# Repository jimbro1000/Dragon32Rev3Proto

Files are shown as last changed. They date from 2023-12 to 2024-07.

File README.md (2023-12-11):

# DRAGON 32 RECREATION Rev 3 #

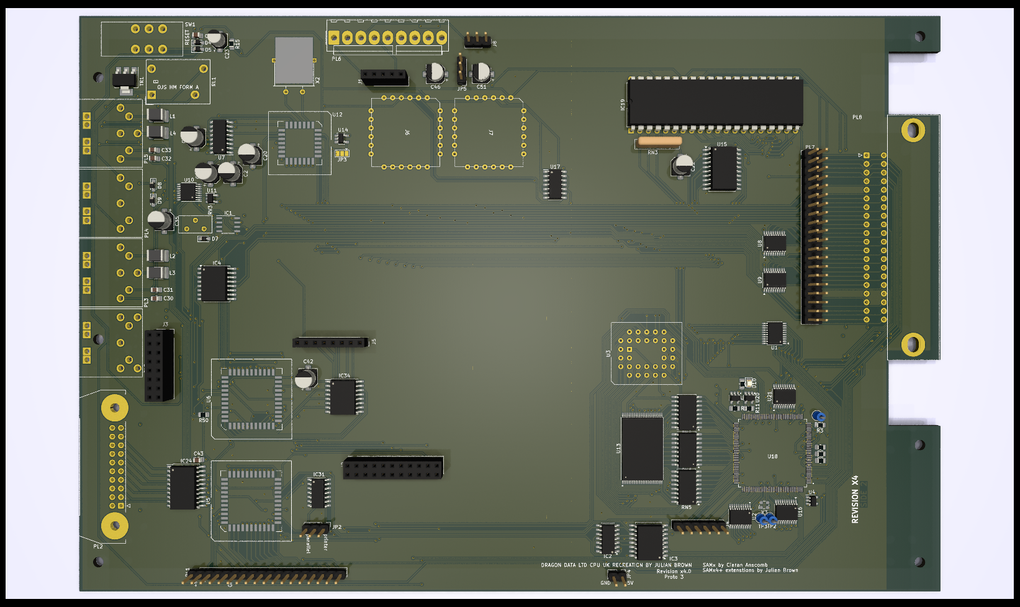
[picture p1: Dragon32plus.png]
Dragon 32 revision 3 render


This project started as a recreation of the SA2120 CPU Mainboard
for the 1982 Dragon Data **Dragon 32**

Everything (excluding modifications) is taken from the SA2120
schematics. Where this version changes is the move to surface
mount components which radically alters the size of each part
along with a move to using SRAM instead of DRAM. The intention
is that the board should be supplied fully or semi-populated
leaving just optional (socketed) components to be fitted.

The ROM is now a single 28C256 eprom with an option to switch
between two images using JP6 or to allow the rom to be
automatically selected from the PIA. In effect this allows the
computer to operate as a D32 but with two different images or
as a D64.

The video circuits have been isolated from the rest of the
board to improve output quality.

To maintain compatibility with the D64 there is an optional
serial port. This needs to be enabled by bridging a solder
jumper (JP3) to position 1-2. If the serial port is not
being populated it should be position 2-3. By default this
is not bridged and the computer will not function without
the jumper being set. If the supporting SMD ICs at U13 and
U14 are fitted the jumper can safely be left in position
1-2 regardless of whether the 6551 UART chip is fitting.

If you are fitting the board into an
early D32 case the serial port would be completely covered
without modifying the case. Later D32 cases had all four
ports but the fourth (serial) port blanked off internally.

A second (internal) cartridge port has been added, by way of
a 2x20 header, along with an additional +5V/Gnd pickup point
for further internal expansion. The keyboard connector also
has two additional pins that can supply 5v to the keyboard,
the extra pins are on the left. The keyboard should always 
be fitted to the right to avoid any shorts.

The board incorporates a replacement to the SAM chip based on
Ciaran Anscomb's SAMx4 design which in turn includes Stewart
Orchards 256k banker board 
<https://gitlab.com/sorchard001/dragon-256k-banker-board>

A custom VHDL is needed for this. Do not use the code from
Ciaran's site as it won't work.

The VHDL has potential (untried as of yet) to allow the
board to run permanently at double speed without loss of
a working display. The potential extends to running at 4x
speed but this is subject to using a suitable CPU and SRAM.

Because all of the CPU speed control is managed by the CPLD
replacing the SAM it is possible to change and update the
VHDL programming to include new features provided they do
not need changes to the board itself. Running at x4 speed
would require a different oscillator at X1 but would not
need other changes. All of the specified components are 
modern high performance equivalents and should be easily
able to cope with the high clock frequencies.

The board also includes three PIAs but only the first two are
necessary for normal usage. The third PIA (U7) is used by some
of the video daughterboards to provide additional functionality
such as a programmable character "rom".

All of the PIAs are changed to the W65C21 chip instead of the
MC6821. These chips work at higher frequencies and conveniently
use a smaller PLCC package

## Progress ##

In the current state (3.0) only the basics of the board have
been tested and proven. 

To be tested:

* SRAM conversion
* Serial port
* PIA 3
* SAMx4

## Modifications ##

### Joysticks ###

The two joystick ports provide a second fire button capability
wired to consecutive keyboard rows, as per the Tandy CoCo.
Unless a two button joystick is used this make no difference to
the operation of the computer. It also requires the use of 6-pin
DIN sockets, these are pin compatible with the 5-pin originals
so a regular single button joystick can still be used.

The two extra buttons can also be disabled by omitting L3 and L4.

### Parallel Port ###

A jumper (JP2) has been introduced to bypass the logic inverter
on the STROBE line. When bypassed the parallel port should
operate as a communication port for DRIVEWIRE.

### Memory Addressing ###

The board is configurable between 32k and 64k ram addressing
using jumper JP1. In most scenarios there is no reason to
disable the 64k option.

### Video PIA ###

One of the possible features of the board is to support an
extended version of the video circuitry to include 
external character ram. Adding a third PIA to the board takes
a little refinement of how PIAs are interfaced. In this case
the mapped memory for PIA1 is broken into 8 blocks, this first
maps to the original memory space for PIA1 while the other 7 
are effectively available to more registers. On this board
only the first of those 7 is used (yet). This makes addresses
$FF44-$FF47 map to the new PIA (referenced here as 1b).

Register A of PIA1b is control of additional functions  
bit 0 controls internal or external character image generation  
bit 1 controls automatic invert on bit 6 of the data bus  
bit 2 is manual control of the invert signal  
bit 3 controls automatic semigraphics on bit 7 of the data bus  
bit 4 is manual control of the semigraphics signal  
bit 5 opens the external character ram to writing  
bit 6 is a clock trigger to the external character ram address  
bit 7 is unused (proposed to be CoCo compatibility switch for 
the keyboard)  

Register B of PIA1b is used for programming the external
character ram data.

The external character ram can only be programmed while the
video is set to the internal character data of the 6847.

### Serial Port ###

The board includes the serial port capability originally
added to the D64. This adds a dedicated 6551 UART chip
to the machine allowing serial communications at higher
speeds without locking out the CPU. The port is optional.

To allow this to work the board *must* user a D64 power
board that supplies -12V instead of -5V. It is possible
to rig the board to work by bridging two pins (2 and 3)
of REG1 but this is not the intended mode of operation.
If the board is rigged for -5V supply then REG1, C18
and C19 must be left unpopulated.

## Substitutions ##

All of the components specified with the exception of
the CPU are current and should be readily available.
Supplies of 6809 CPUs are still plentiful but are all
NOS.

The Hitachi HD6309 is usable but may cause crashes in 
some software due to lazy coding. It is however still 
made thanks to usage in old military equipment in at
least one country.

### The Future ###

The board may look empty in its current form but the design
is dominated by the main data and address busses.

The design will also include two AY8912 audio chips to 
provide stereo sound. This brings utilisation of the 
additional device addressing to 50% but also fills up
the remainder of the board.

It is possible to increase the size of the board along
the bottom edge as the current design complies with the
original D32 design rather than the enlarged D64 board.

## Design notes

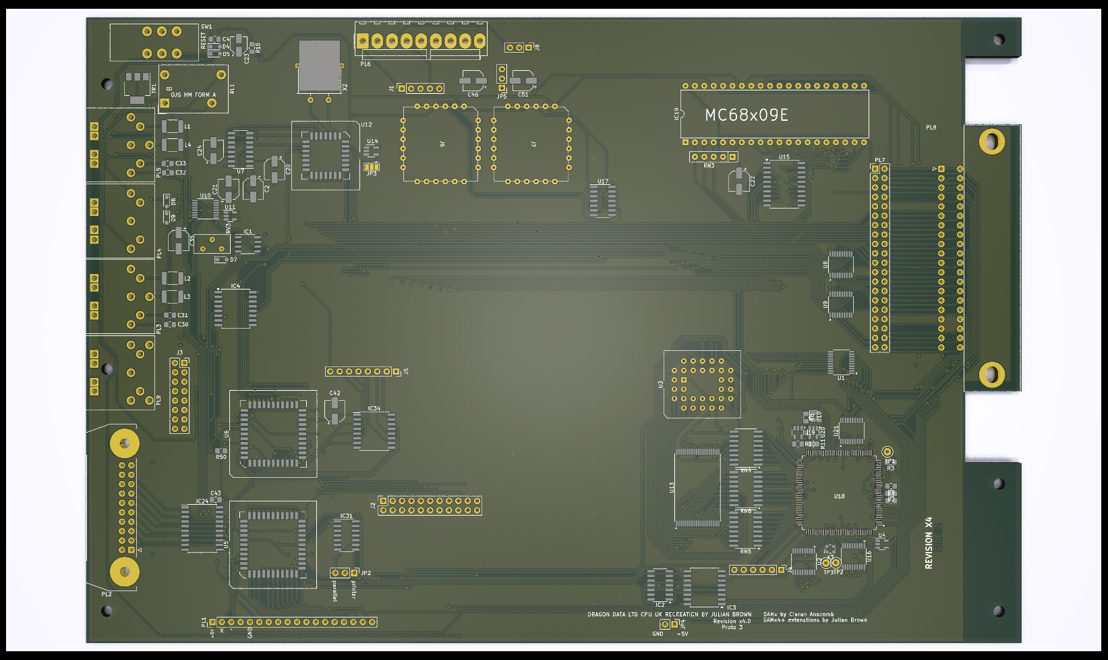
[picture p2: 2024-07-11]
Dragon32.png

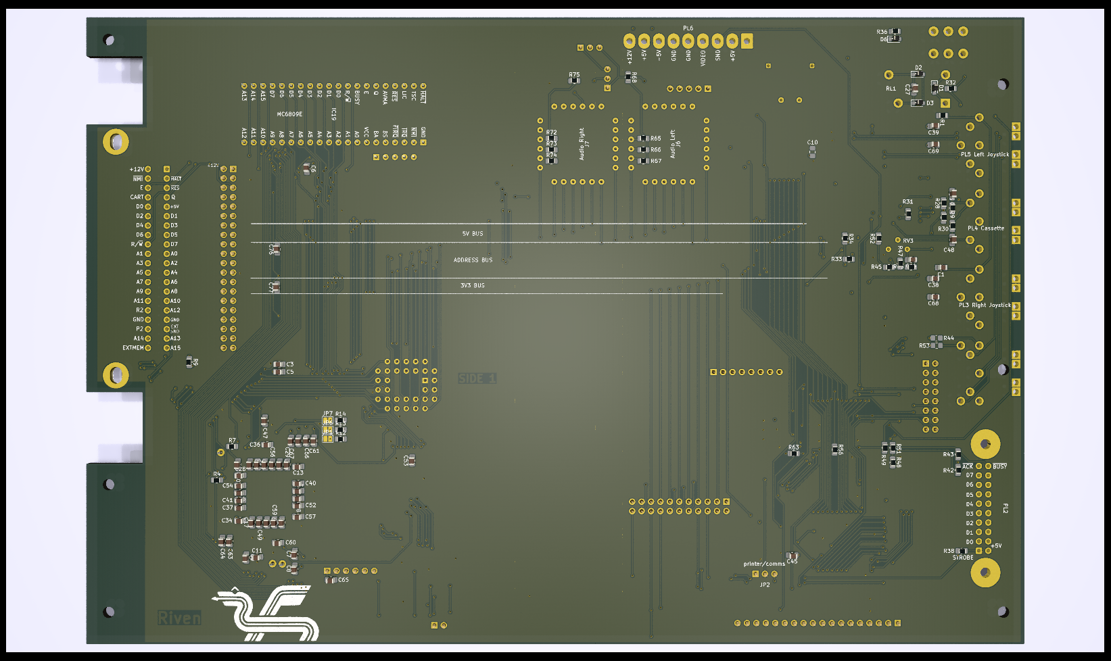
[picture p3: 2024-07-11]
Dragon32plusR.png

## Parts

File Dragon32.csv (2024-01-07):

Source: | C:\Users\jimbr\OneDrive\Documents\KiCad\7.0\projects\Dragon32Alpha3\Dragon32.kicad_sch
Date: | 17/12/2023 11:29:43
Tool: | Eeschema 7.0.6
Generator: | C:\Program Files\KiCad\7.0\bin\scripting\plugins/bom_csv_grouped_by_value.py
Component Count: | 183
Collated Components:
Item | Qty | Reference(s) | Value | LibPart | Footprint | Datasheet | DNP | DigiKey | JLCPCB BOM | LCSC Part | Mouser | Note | SA2120 | Toby
1 | 7 | C1, C38, C39, C43, C45, C68, C69 | 0.01uF | Device:C_Small | Capacitor_SMD:C_0805_2012Metric_Pad1.18x1.45mm_HandSolder | https://www.vishay.com/docs/45171/kseries.pdf |  | BC2662CT-ND
2 | 3 | C2, C35, C42 | 10uF | Device:C_Polarized_Small | Capacitor_SMD:CP_Elec_5x5.3 | https://www.we-online.com/katalog/datasheet/860010372001.pdf |  | 732-8593-1-ND
3 | 4 | C3, C4, C5, C27 | 0.1uF | Device:C_Small | Capacitor_SMD:C_0805_2012Metric_Pad1.18x1.45mm_HandSolder | https://www.vishay.com/docs/45171/kseries.pdf |  | BC1101CT-ND
4 | 1 | C6 | 4.7uF | Device:C_Polarized_Small | Capacitor_Tantalum_SMD:CP_EIA-3216-18_Kemet-A_Pad1.58x1.35mm_HandSolder | https://datasheets.kyocera-avx.com/tap.pdf |  | 478-8984-1-ND
5 | 7 | C7, C11, C12, C13, C14, C15, C16 | 100n | Device:C | Capacitor_SMD:C_0805_2012Metric_Pad1.18x1.45mm_HandSolder | ~ |  |  | 0 | C149620
6 | 1 | C8 | 1u | Device:C | Capacitor_SMD:C_0805_2012Metric_Pad1.18x1.45mm_HandSolder | ~ |  |  |  | C77080
7 | 1 | C9 | 2u2 | Device:C | Capacitor_SMD:C_0805_2012Metric_Pad1.18x1.45mm_HandSolder | ~ |  |  |  | C961513
8 | 2 | C10, C17 | 100n | Device:C_Small | Capacitor_SMD:C_0805_2012Metric_Pad1.18x1.45mm_HandSolder | ~ | DNP
9 | 2 | C18, C19 | 1u | Device:C_Polarized | Capacitor_Tantalum_SMD:CP_EIA-3216-18_Kemet-A_Pad1.58x1.35mm_HandSolder | ~
10 | 1 | C22 | 100uF | Device:C_Polarized_Small | Capacitor_SMD:CP_Elec_5x5.3 | https://www.we-online.com/katalog/datasheet/860010372006.pdf |  | 732-8598-1-ND
11 | 1 | C23 | 1uF | Device:CP_Small | Capacitor_SMD:CP_Elec_4x4.5 | https://www.we-online.com/katalog/datasheet/860020772005.pdf |  | 732-8541-1-ND
12 | 1 | C26 | 2.2nF | Device:C_Small | Capacitor_SMD:C_0805_2012Metric_Pad1.18x1.45mm_HandSolder | https://www.vishay.com/docs/45171/kseries.pdf |  | BC1074CT-ND
13 | 5 | C30, C31, C32, C33, C44 | 22nF | Device:C_Small | Capacitor_SMD:C_0805_2012Metric_Pad1.18x1.45mm_HandSolder | https://www.vishay.com/docs/45171/kseries.pdf |  | BC2677CT-ND
14 | 2 | C46, C51 | 10uF | Device:C_Polarized_Small | Capacitor_SMD:CP_Elec_5x3 | ~
15 | 1 | C48 | 22pF | Device:C_Small | Capacitor_SMD:C_0805_2012Metric_Pad1.18x1.45mm_HandSolder | https://connect.kemet.com:7667/gateway/IntelliData-ComponentDocumentation/1.0/download/datasheet/C315C220K2G5TA7301 |  | 399-13930-1-ND
16 | 6 | D1, D2, D3, D7, D8, D9 | 1N914 | Device:D_Small_Filled | Diode_SMD:D_SOD-323_HandSoldering | http://www.vishay.com/docs/85622/1n914.pdf |  | 1N914FS-ND
17 | 3 | D4, D5, D6 | 1N914 | Diode:1N914 | Diode_SMD:D_SOD-323_HandSoldering | http://www.vishay.com/docs/85622/1n914.pdf |  | 1N914FS-ND
18 | 8 | D10, D11, D12, D13, D14, D15, D16, D17 | 1N914 | Device:D_Small_Filled | Diode_SMD:D_SOD-323_HandSoldering | http://www.vishay.com/docs/85622/1n914.pdf | DNP | 1N914FS-ND
19 | 1 | IC1 | LM393DR | Comparator:LM393 | Package_SO:SOP-8_3.9x4.9mm_P1.27mm | http://www.ti.com/lit/ds/symlink/lm393.pdf |  | 296-1015-1-ND
20 | 1 | IC10 | 74ACT138 | 74xx:74LS138 | Package_SO:SOIC-16W_7.5x10.3mm_P1.27mm | http://www.ti.com/lit/gpn/sn74LS138 |  | 74ACT138SCXCT-ND
21 | 3 | IC11, IC16, IC24 | 74ACT244N | 74xx:74LS244 | Package_SO:SOIC-20W_7.5x12.8mm_P1.27mm | http://www.ti.com/lit/ds/symlink/sn74ls244.pdf |  | 74ACT244SCXCT-ND |  |  |  |  | Sheet 1
22 | 1 | IC19 | MC6809E | CPU_NXP_6800:MC6809E | Package_DIP:DIP-40_W15.24mm | http://pdf.datasheetcatalog.com/datasheet/motorola/MC68B09S.pdf |  |  |  |  |  | donor | Sheet 1
23 | 1 | IC31 | 74ACT02 | 74xx:74LS02 | Package_SO:SOIC-14_3.9x8.7mm_P1.27mm | http://www.ti.com/lit/gpn/sn74ls02 |  | MC74ACT02DR2GOSCT-ND |  |  |  |  | Sheet 1 (spare)
24 | 1 | IC33 | 74ACT138N | 74xx:74LS138 | Package_SO:SOIC-16W_7.5x10.3mm_P1.27mm | http://www.ti.com/lit/gpn/sn74LS138 |  | 74ACT138SCXCT-ND |  |  |  |  | Sheet 1
25 | 1 | IC34 | CD4050BDR | Motorola PIA:MC14050BCP | Package_SO:SOIC-16W_7.5x10.3mm_P1.27mm | https://media.digikey.com/pdf/Data%20Sheets/ON%20Semiconductor%20PDFs/MC14049B,50B_Rev7.pdf |  | 296-31503-1-ND
26 | 1 | J1 | Video Output Female | Connector:Conn_01x05_Pin | Connector_PinSocket_2.54mm:PinSocket_1x05_P2.54mm_Vertical | ~
27 | 1 | J2 | Board Interconnect Female | Connector_Generic:Conn_02x11_Odd_Even | Connector_PinSocket_2.54mm:PinSocket_2x11_P2.54mm_Vertical | ~
28 | 1 | J3 | Conn_02x08_Odd_Even | Connector_Generic:Conn_02x08_Odd_Even | Connector_PinSocket_2.54mm:PinSocket_2x08_P2.54mm_Vertical | ~
29 | 1 | J4 | JTAG | Connector_Generic:Conn_01x06 | Connector_PinHeader_2.54mm:PinHeader_1x06_P2.54mm_Vertical | ~ |  |  | 0
30 | 1 | J5 | 6-bit DAC | Connector_Generic:Conn_01x08 | Connector_PinSocket_2.54mm:PinSocket_1x08_P2.54mm_Vertical | ~
31 | 1 | J6 | Audio Left | Connector_Generic:Conn_01x24 | Dragon:AY-QTHT | ~
32 | 1 | J7 | Audio Right | Connector_Generic:Conn_01x24 | Dragon:AY-QTHT | ~
33 | 1 | J8 | Stereo | Connector:Conn_01x03_Pin | Connector_PinHeader_2.54mm:PinHeader_1x03_P2.54mm_Vertical | ~
34 | 1 | JP1 | 32k/64k | Jumper:Jumper_3_Bridged12 | Connector_PinHeader_2.54mm:PinHeader_1x03_P2.54mm_Vertical | ~
35 | 1 | JP2 | printer/comms | Jumper:Jumper_3_Bridged12 | Connector_PinHeader_2.54mm:PinHeader_1x03_P2.54mm_Vertical | ~
36 | 1 | JP3 | Serial | Jumper:SolderJumper_3_Open | Jumper:SolderJumper-3_P1.3mm_Open_Pad1.0x1.5mm | ~
37 | 1 | JP4 | 5vPower | Connector:Conn_01x02_Pin | Connector_PinHeader_2.54mm:PinHeader_1x02_P2.54mm_Vertical | ~
38 | 1 | JP5 | Jumper_3_Open | Jumper:Jumper_3_Open | Connector_PinHeader_2.54mm:PinHeader_1x03_P2.54mm_Vertical | ~
39 | 1 | JP6 | ROM A14 | vdg:Jumper_4 | Dragon:Jumper_4
40 | 4 | L1, L2, L3, L4 | 3.3uH | Device:FerriteBead_Small | Inductor_SMD:L_1812_4532Metric_Pad1.30x3.40mm_HandSolder | ~ |  | 495-5561-1-ND
41 | 1 | PL1 | Conn_01x18_Pin | Connector:Conn_01x18_Pin | Connector_PinHeader_2.54mm:PinHeader_1x18_P2.54mm_Vertical | ~
42 | 1 | PL2 | Printer | Connector_Generic:Conn_02x10_Top_Bottom | Connector_IDC:IDC-Header_2x10-1MP_P2.54mm_Latch_Horizontal | https://media.digikey.com/pdf/Data%20Sheets/CW%20Industries%20PDFs/CWN-300%20Ordering.pdf |  | CHR20G-ND |  |  |  | or 1195-1707-ND with latches
43 | 1 | PL3 | DIN-6 J/S R | Connector:DIN-6 | Dragon:DIN-6_DELTRON_671-0601_Horizontal | https://www.dem-uk.com/deltron-components/Data/Product_Downloads/deltron-671-0501-5-way-din-socket-data.pdf |  |  |  |  |  | RS Components
44 | 1 | PL4 | DIN-5 (180) Cassette | Connector:DIN-5_180degree | Dragon:DIN-5_DELTRON_671-0501_45deg_Horizontal | https://www.dem-uk.com/deltron-components/Data/Product_Downloads/deltron-671-0501-5-way-din-socket-data.pdf |  |  |  |  |  | RS Components
45 | 1 | PL5 | DIN-6 J/S L | Connector:DIN-6 | Dragon:DIN-6_DELTRON_671-0601_Horizontal | https://www.dem-uk.com/deltron-components/Data/Product_Downloads/deltron-671-0501-5-way-din-socket-data.pdf |  |  |  |  |  | RS Components
46 | 1 | PL6 | Conn_01x09_Male | Connector:Conn_01x09_Male | Connector_Molex:Molex_KK-396_A-41791-0009_1x09_P3.96mm_Vertical | https://app.adam-tech.com/products/download/data_sheet/241222/lhd-xx-ts-data-sheet.pdf |  | 2057-LHD-09-TS-ND |  |  |  |  |  | WH396-09S-010
47 | 1 | PL7 | EDAC 392-040-558-201 | Connector_Generic:Conn_01x40 | Dragon:Edge_2x20_P2.54mm_OvalMP | https://files.edac.net/edac/content/342/342-040-558-212%20-%20EDAC%20Card%20Edge%20Connector.PDF |  | 151-395-040-558-201-ND |  |  | 587-395-040-558-201
48 | 1 | PL8 | EDAC 392-040-558-201 | Connector_Generic:Conn_01x40 | Connector_PinHeader_2.54mm:PinHeader_2x20_P2.54mm_Vertical | ~ |  | 151-395-040-558-201-ND |  |  | 587-395-040-558-201
49 | 1 | PL9 | Serial | dragon64:DIN-7-MP | Dragon:DIN-7_DELTRON_671-0701_Horizontal | http://www.mouser.com/ds/2/18/40_c091_abd_e-75918.pdf | DNP
50 | 2 | R1, R5 | 100R | Device:R_Small | Resistor_SMD:R_0805_2012Metric_Pad1.20x1.40mm_HandSolder | ~ |  | CF14JT100RCT-ND
51 | 21 | R2, R3, R4, R6, R7, R8, R9, R10, R11, R12, R17, R18, R19, R20, R21, R22, R23, R24, R25, R26, R27 | 22R | Device:R_Small | Resistor_SMD:R_0805_2012Metric_Pad1.20x1.40mm_HandSolder | ~ |  | CF14JT22R0CT-ND
52 | 10 | R13, R14, R28, R30, R32, R38, R39, R40, R41, R63 | 4K7 | Device:R_Small | Resistor_SMD:R_0805_2012Metric_Pad1.20x1.40mm_HandSolder | ~ |  | CF14JT4K70CT-ND
53 | 2 | R15, R36 | 100K | Device:R | Resistor_SMD:R_0805_2012Metric_Pad1.20x1.40mm_HandSolder | ~ |  | CF14JT100KCT-ND
54 | 1 | R16 | 33K | Device:R_Small | Resistor_SMD:R_0805_2012Metric_Pad1.20x1.40mm_HandSolder | ~ |  | CF14JT33K0CT-ND
55 | 1 | R29 | 68K | Device:R_Small | Resistor_SMD:R_0805_2012Metric_Pad1.20x1.40mm_HandSolder | ~ |  | CF14JT68K0CT-ND
56 | 4 | R31, R42, R43, R56 | 10K | Device:R_Small | Resistor_SMD:R_0805_2012Metric_Pad1.20x1.40mm_HandSolder | ~ |  | CF14JT10K0CT-ND
57 | 1 | R33 | 10M | Device:R_Small | Resistor_SMD:R_0805_2012Metric_Pad1.20x1.40mm_HandSolder | ~ |  | CF14JT10M0CT-ND
58 | 10 | R34, R49, R65, R66, R67, R68, R72, R73, R74, R75 | 1K | Device:R_Small | Resistor_SMD:R_0805_2012Metric_Pad1.20x1.40mm_HandSolder | ~ |  | CF14JT1K00CT-ND
59 | 2 | R35, R37 | 47R | Device:R_Small | Resistor_SMD:R_0805_2012Metric_Pad1.20x1.40mm_HandSolder | ~ | DNP | CF14JT4K70CT-ND
60 | 4 | R44, R53, R54, R55 | 4K7 | Device:R_Small | Resistor_SMD:R_0805_2012Metric_Pad1.20x1.40mm_HandSolder | ~ | DNP | CF14JT4K70CT-ND
61 | 1 | R45 | 6K8 | Device:R_Small | Resistor_SMD:R_0805_2012Metric_Pad1.20x1.40mm_HandSolder | ~ |  | CF14JT6K80CT-ND
62 | 1 | R46 | 220R | Device:R_Small | Resistor_SMD:R_0805_2012Metric_Pad1.20x1.40mm_HandSolder | ~ |  | CF14JT220RCT-ND
63 | 1 | R47 | 8K2 | Device:R_Small | Resistor_SMD:R_0805_2012Metric_Pad1.20x1.40mm_HandSolder | ~ |  | CF14JT8K20CT-ND
64 | 1 | R48 | 15K | Device:R_Small | Resistor_SMD:R_0805_2012Metric_Pad1.20x1.40mm_HandSolder | ~ |  | CF14JT15K0CT-ND
65 | 2 | R50, R52 | 56K | Device:R_Small | Resistor_SMD:R_0805_2012Metric_Pad1.20x1.40mm_HandSolder | ~ |  | CF14JT56K0CT-ND
66 | 1 | R51 | 1M5 | Device:R_Small | Resistor_SMD:R_0805_2012Metric_Pad1.20x1.40mm_HandSolder | ~ |  | CF14JT1M50CT-ND
67 | 2 | R57, R58 | 47K | Device:R_Small | Resistor_SMD:R_0805_2012Metric_Pad1.20x1.40mm_HandSolder | ~ | DNP | CF14JT4K70CT-ND
68 | 2 | R59, R60 | 100K | Device:R_Small | Resistor_SMD:R_0805_2012Metric_Pad1.20x1.40mm_HandSolder | ~ | DNP | CF14JT4K70CT-ND
69 | 1 | REG1 | LM79L05_TO92 | Regulator_Linear:LM79L05_TO92 | Package_TO_SOT_SMD:SOT-89-3_Handsoldering | http://www.ti.com/lit/ds/symlink/lm79l.pdf
70 | 1 | RL1 | OJS HM FORM A | Relay:ADW11 | Dragon:OJS HM 10A Relay | https://www.te.com/commerce/DocumentDelivery/DDEController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 |  | 41-OJS-SH-105HMF,00000-ND
71 | 1 | RV3 | 470R | Device:R_Potentiometer | Potentiometer_THT:Potentiometer_Bourns_3386X_Horizontal | ~ |  | 3386H-103LF-ND
72 | 1 | SW1 | RESET | Switch:SW_Push_DPDT | Dragon:Button_AlpsAlpine_SPUN190900 | https://www.ckswitches.com/media/1402/fpush.pdf |  | 401-1225-ND
73 | 1 | TR1 | PZT2222A | Transistor_BJT:PZT2222A | Package_TO_SOT_SMD:SOT-223-3_TabPin2 | https://www.onsemi.com/pub/Collateral/PN2222-D.PDF
74 | 1 | U1 | AS6C1008-TIN | Motorola PIA:AS6C1008 | Package_SO:TSOP-I-32_18.4x8mm_P0.5mm | https://www.alliancememory.com/wp-content/uploads/pdf/AS6C1008feb2007.pdf |  | 1450-1020-ND
75 | 1 | U2 | AS6C1008-55TIN | Motorola PIA:AS6C1008 | Package_SO:TSOP-I-32_18.4x8mm_P0.5mm | https://www.alliancememory.com/wp-content/uploads/pdf/AS6C1008feb2007.pdf |  | 1450-1020-ND
76 | 1 | U3 | XC95144XL-TQ100 | CPLD_Xilinx:XC95144XL-TQ100 | Package_QFP:TQFP-100_14x14mm_P0.5mm | https://www.xilinx.com/support/documentation/data_sheets/ds056.pdf |  |  |  | C45126
77 | 1 | U4 | TPS7A2433DBVR | Regulator_Linear:TPS7A0533PDBV | Package_TO_SOT_SMD:SOT-23-5 | https://www.ti.com/lit/ds/symlink/tps7a05.pdf |  |  |  | C2866134
78 | 3 | U5, U6, U7 | W65C21 | Motorola PIA:W65C21 | Package_LCC:PLCC-44_SMD-Socket
79 | 1 | U8 | 28C256 | BenEater:28C256_PLCC | Package_LCC:PLCC-32_THT-Socket | http://ww1.microchip.com/downloads/en/DeviceDoc/doc0006.pdf
80 | 1 | U9 | 74HCT1G08 | vdg:74HC1G08 | Package_TO_SOT_SMD:SOT-353_SC-70-5_Handsoldering | https://assets.nexperia.com/documents/data-sheet/74HC_HCT1G08.pdf |  | 1727-6053-1-ND
81 | 1 | U10 | 4052 | 4xxx:4052 | Package_SO:TSSOP-16_4.4x5mm_P0.65mm | http://www.intersil.com/content/dam/Intersil/documents/cd40/cd4051bms-52bms-53bms.pdf
82 | 1 | U11 | TS5A3166DBVR | Analog_Switch:TS5A3166DBVR | Package_TO_SOT_SMD:SOT-23-5 | http://www.ti.com/lit/ds/symlink/ts5a3166.pdf
83 | 1 | U12 | 6551 | Motorola PIA:6551 | Package_DIP:DIP-28_W15.24mm |  | DNP
84 | 1 | U13 | 4069 | 4xxx:4069 | Package_SO:SOIC-14_3.9x8.7mm_P1.27mm | http://www.intersil.com/content/dam/Intersil/documents/cd40/cd4069ubms.pdf | DNP
85 | 1 | U14 | LM348DR | Motorola PIA:LM348x | Package_SO:SOIC-14_3.9x8.7mm_P1.27mm |  | DNP
86 | 1 | U17 | 74LS08 | 74xx:74LS08 | Package_SO:SO-14_3.9x8.65mm_P1.27mm | http://www.ti.com/lit/gpn/sn74LS08
87 | 1 | X1 | 14.31818MHz | Oscillator:ECS-2520MV-xxx-xx | Oscillator:Oscillator_SMD_ECS_2520MV-xxx-xx-4Pin_2.5x2.0mm | https://www.ecsxtal.com/store/pdf/ECS-2520MV.pdf |  |  |  | C5119017
88 | 1 | X2 | 1.8432MHz | Device:Crystal_GND3_Small | Crystal:Crystal_HC18-U_Horizontal_1EP_style2 | ~ | DNP

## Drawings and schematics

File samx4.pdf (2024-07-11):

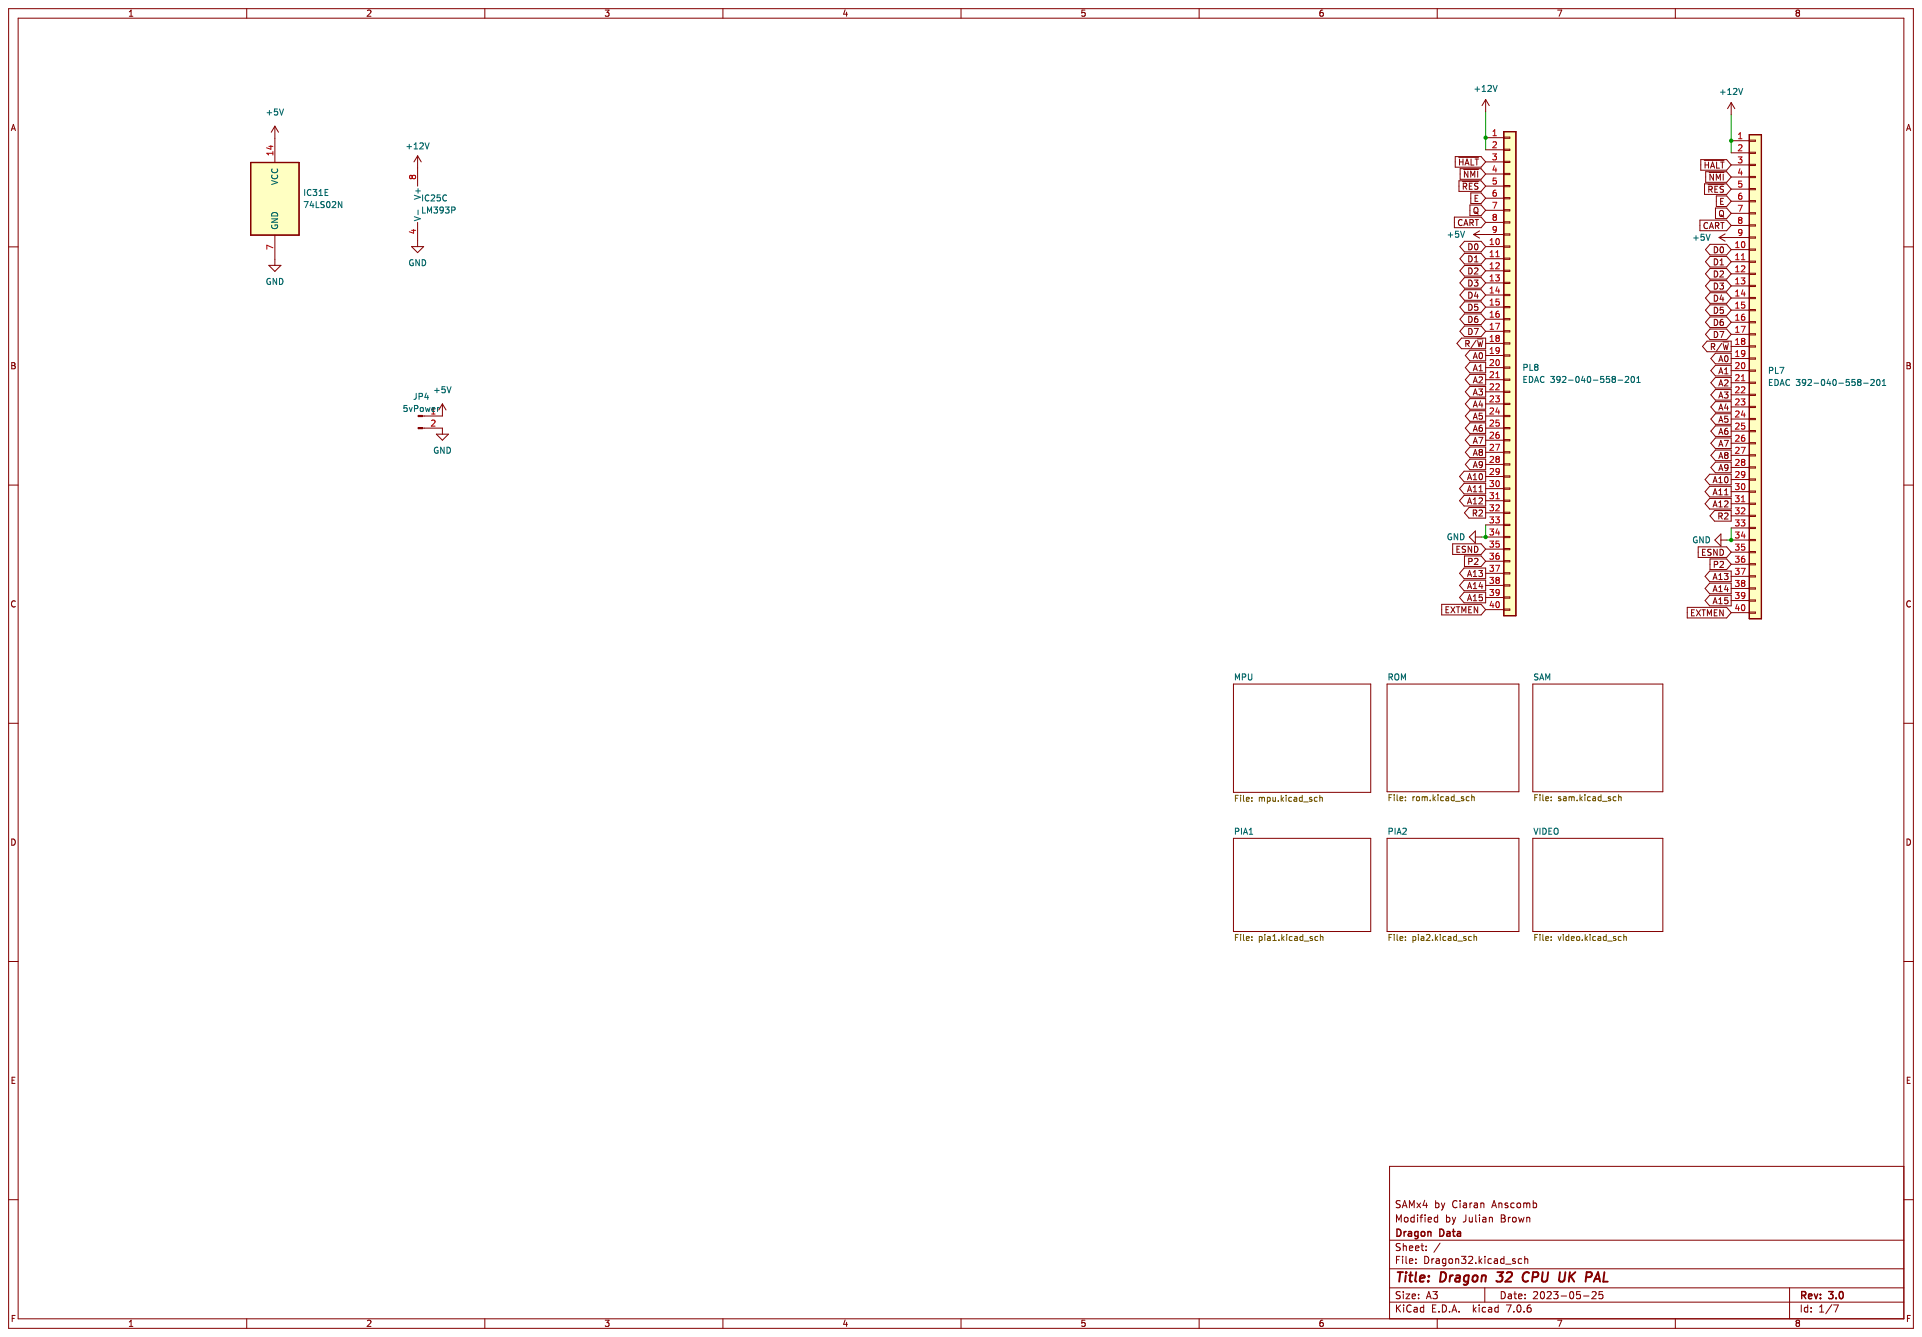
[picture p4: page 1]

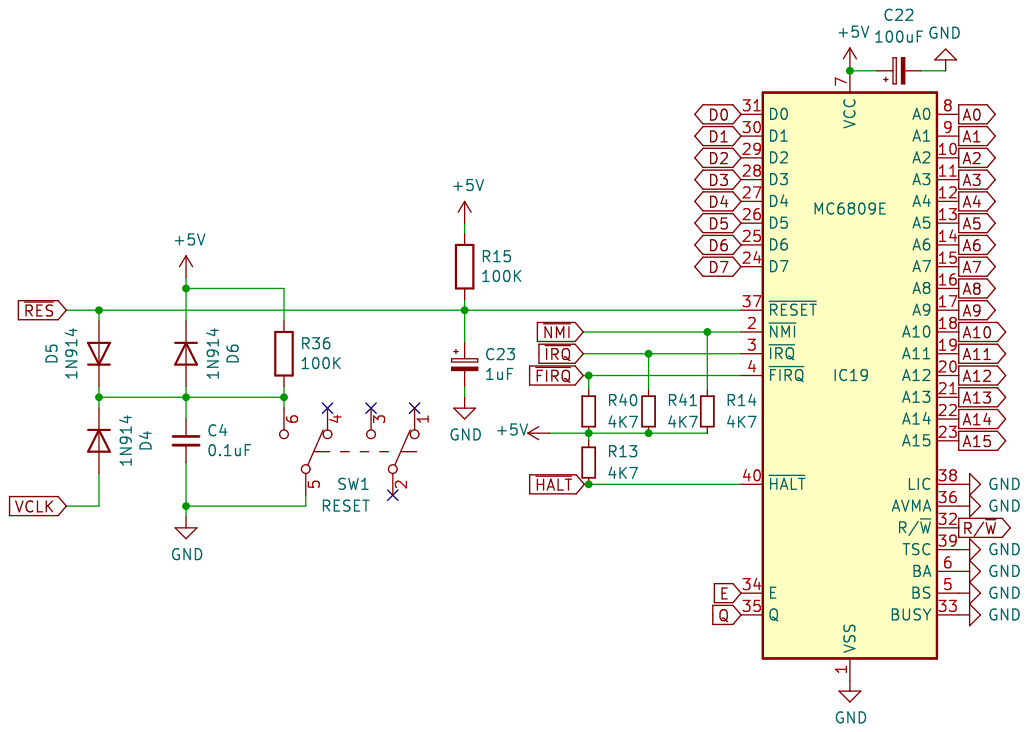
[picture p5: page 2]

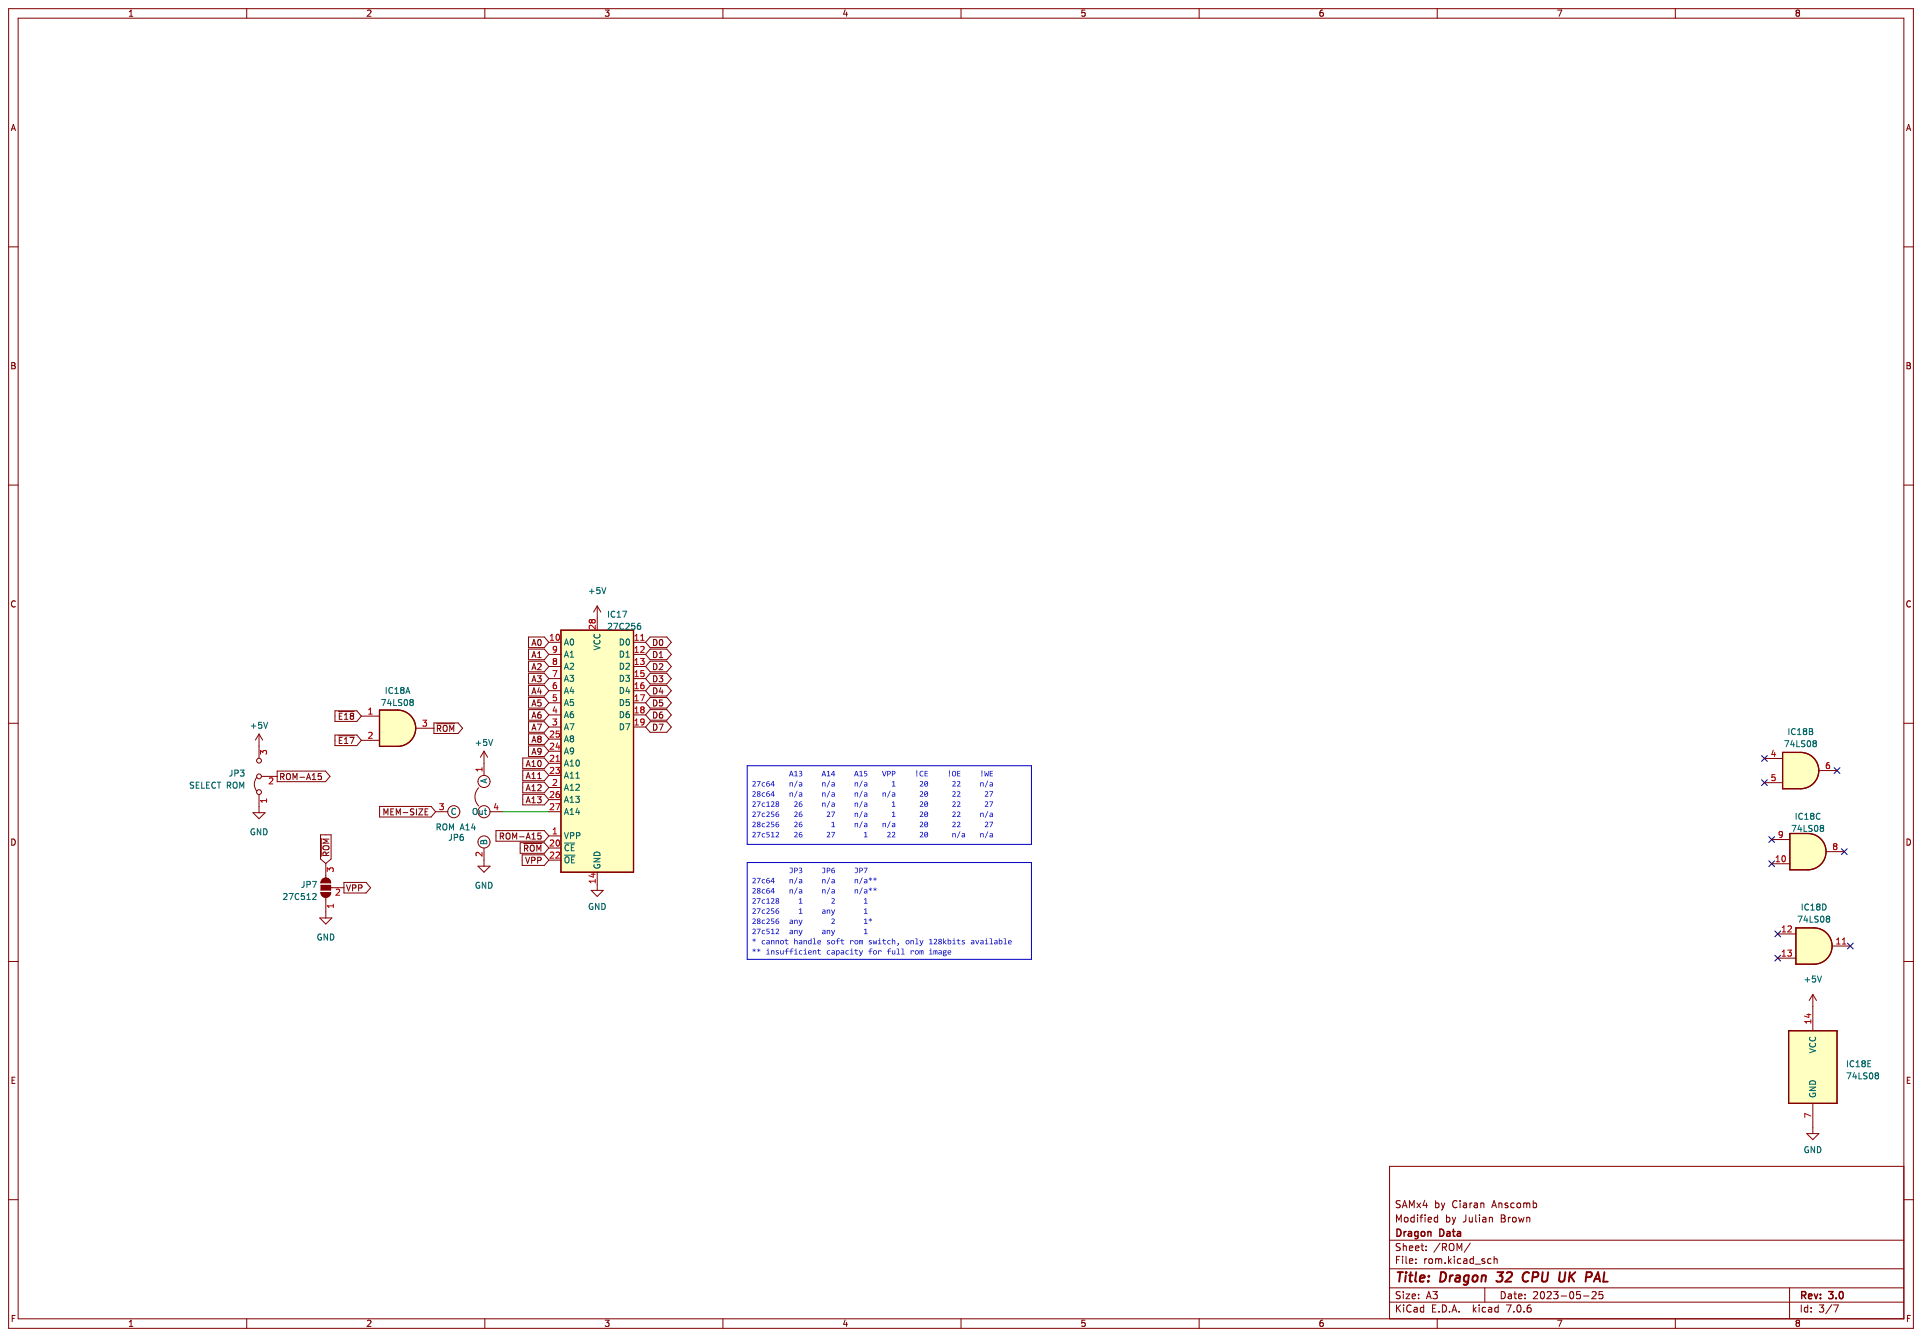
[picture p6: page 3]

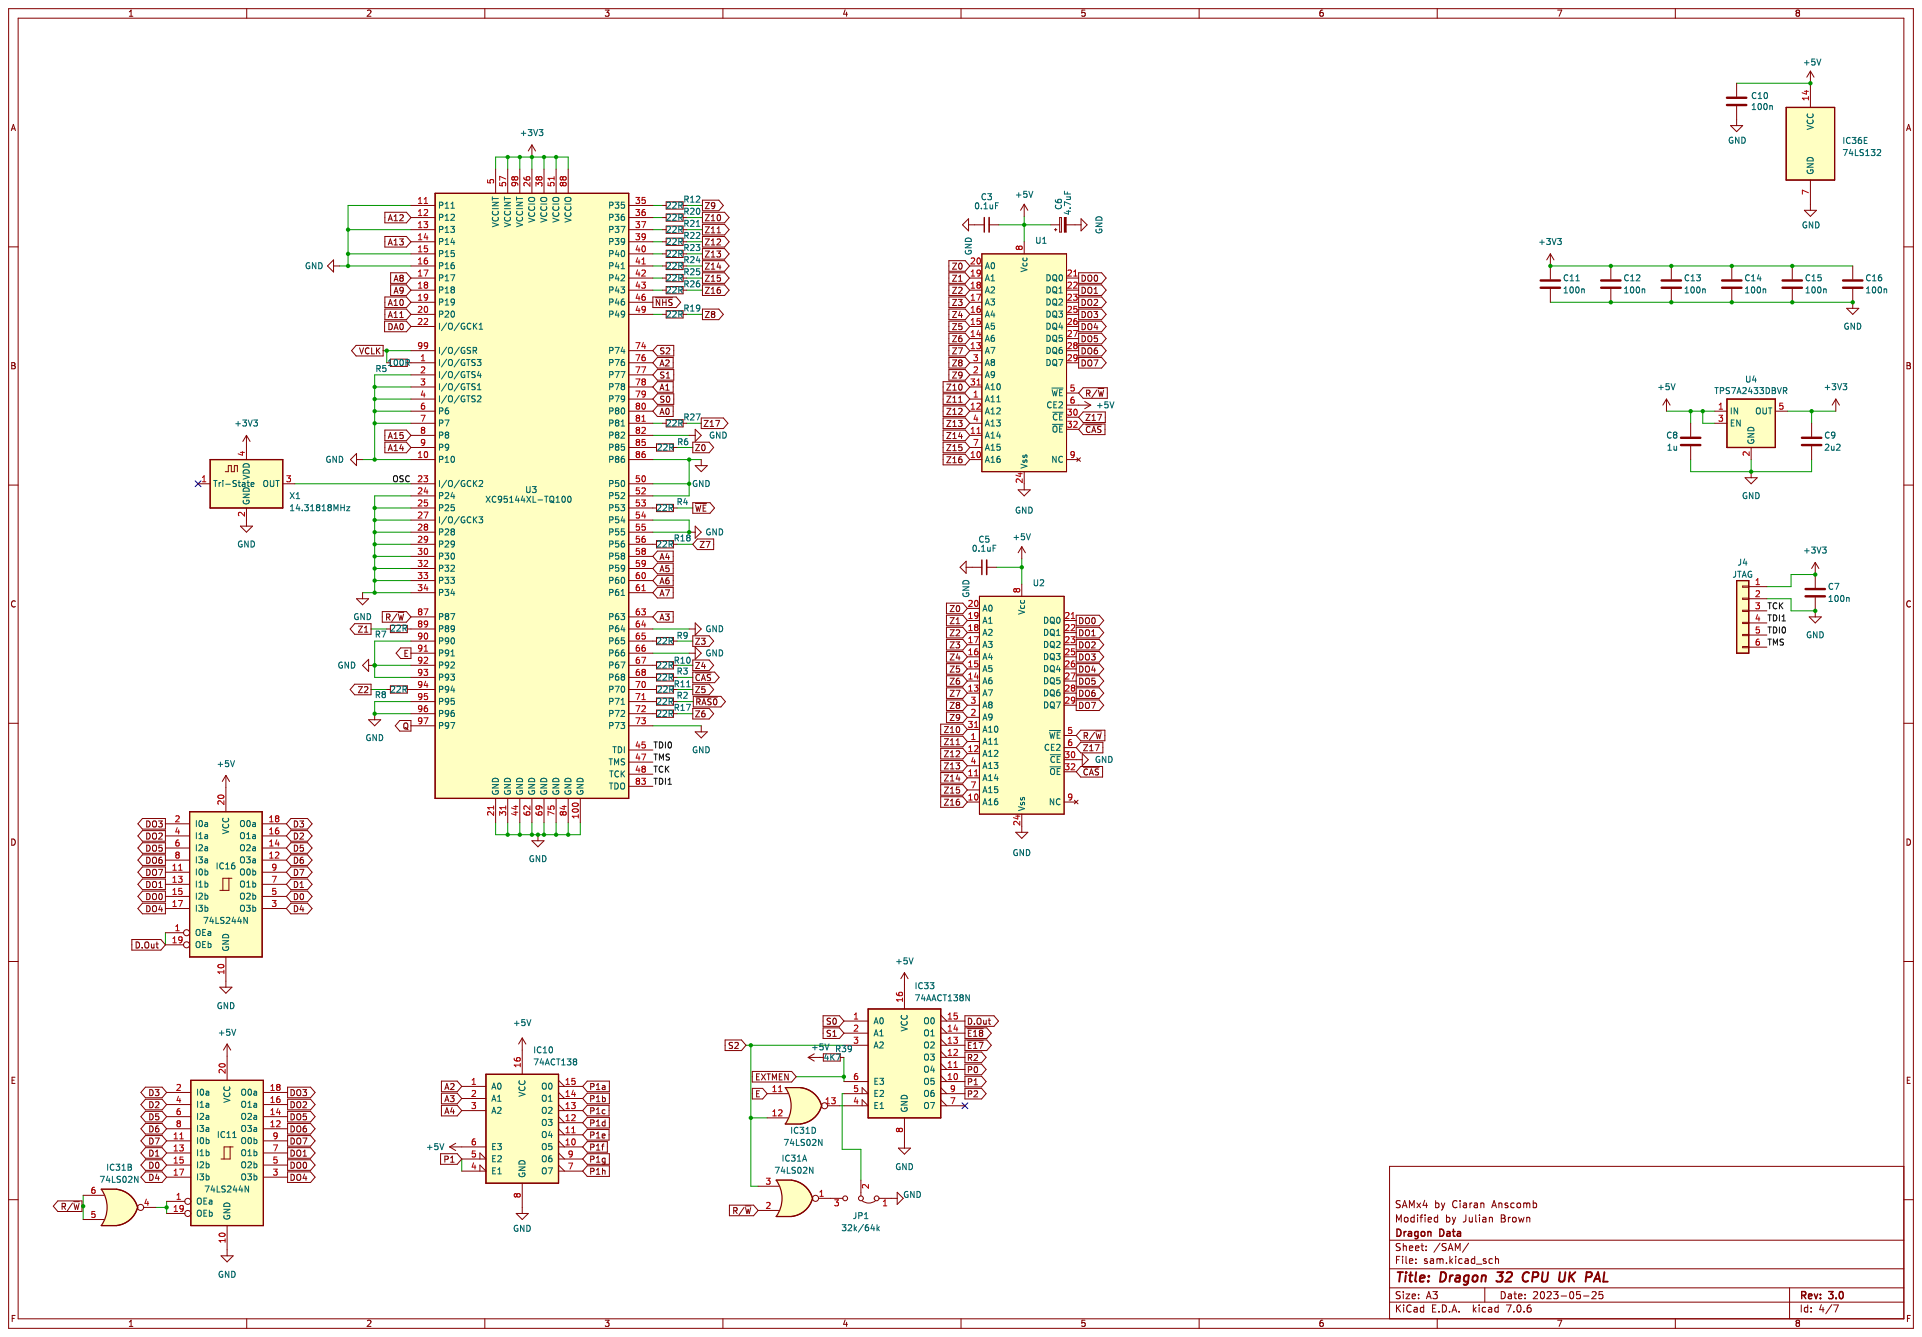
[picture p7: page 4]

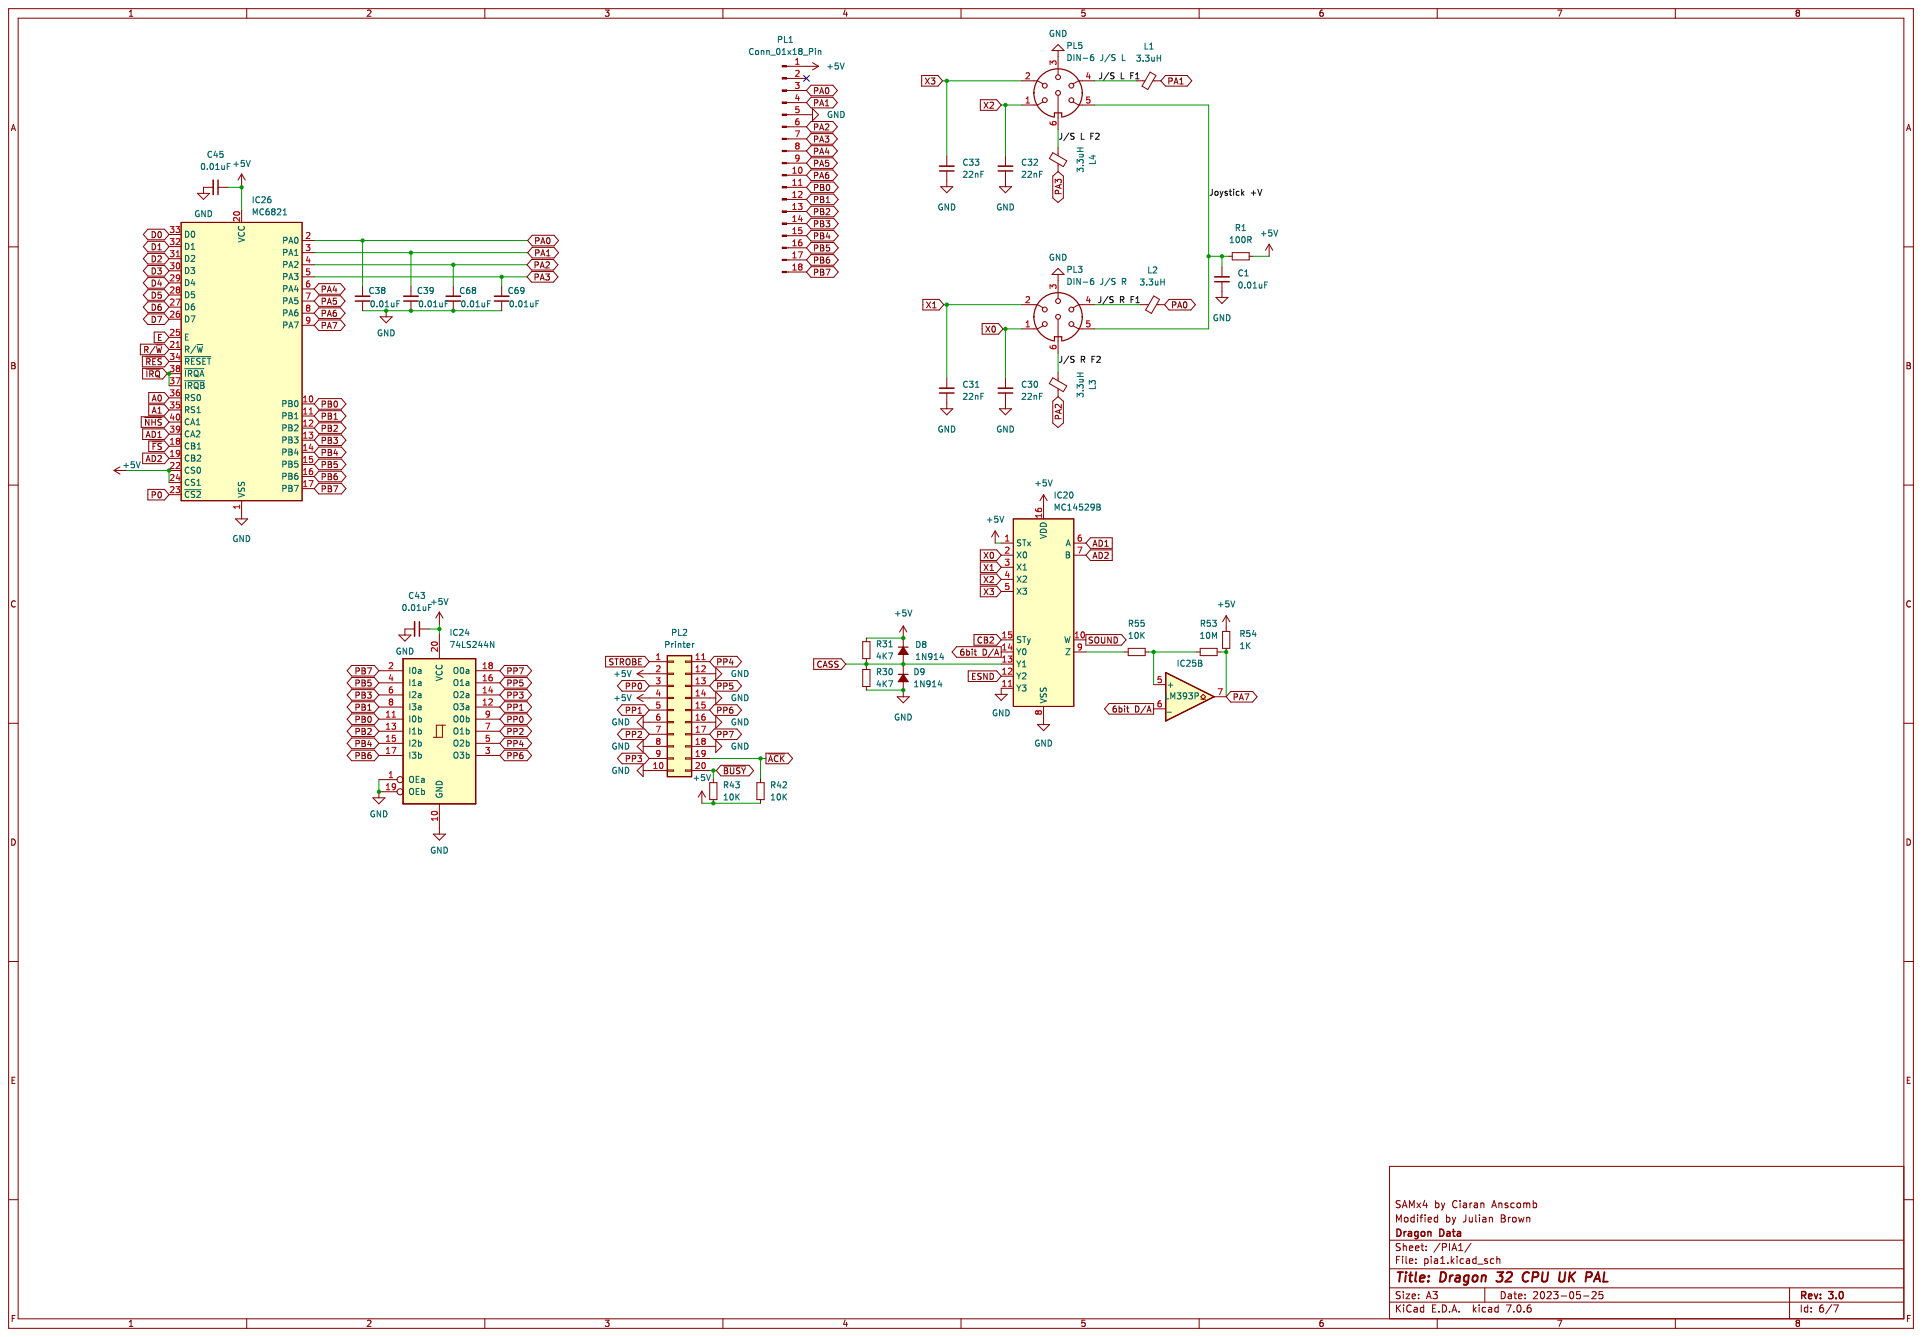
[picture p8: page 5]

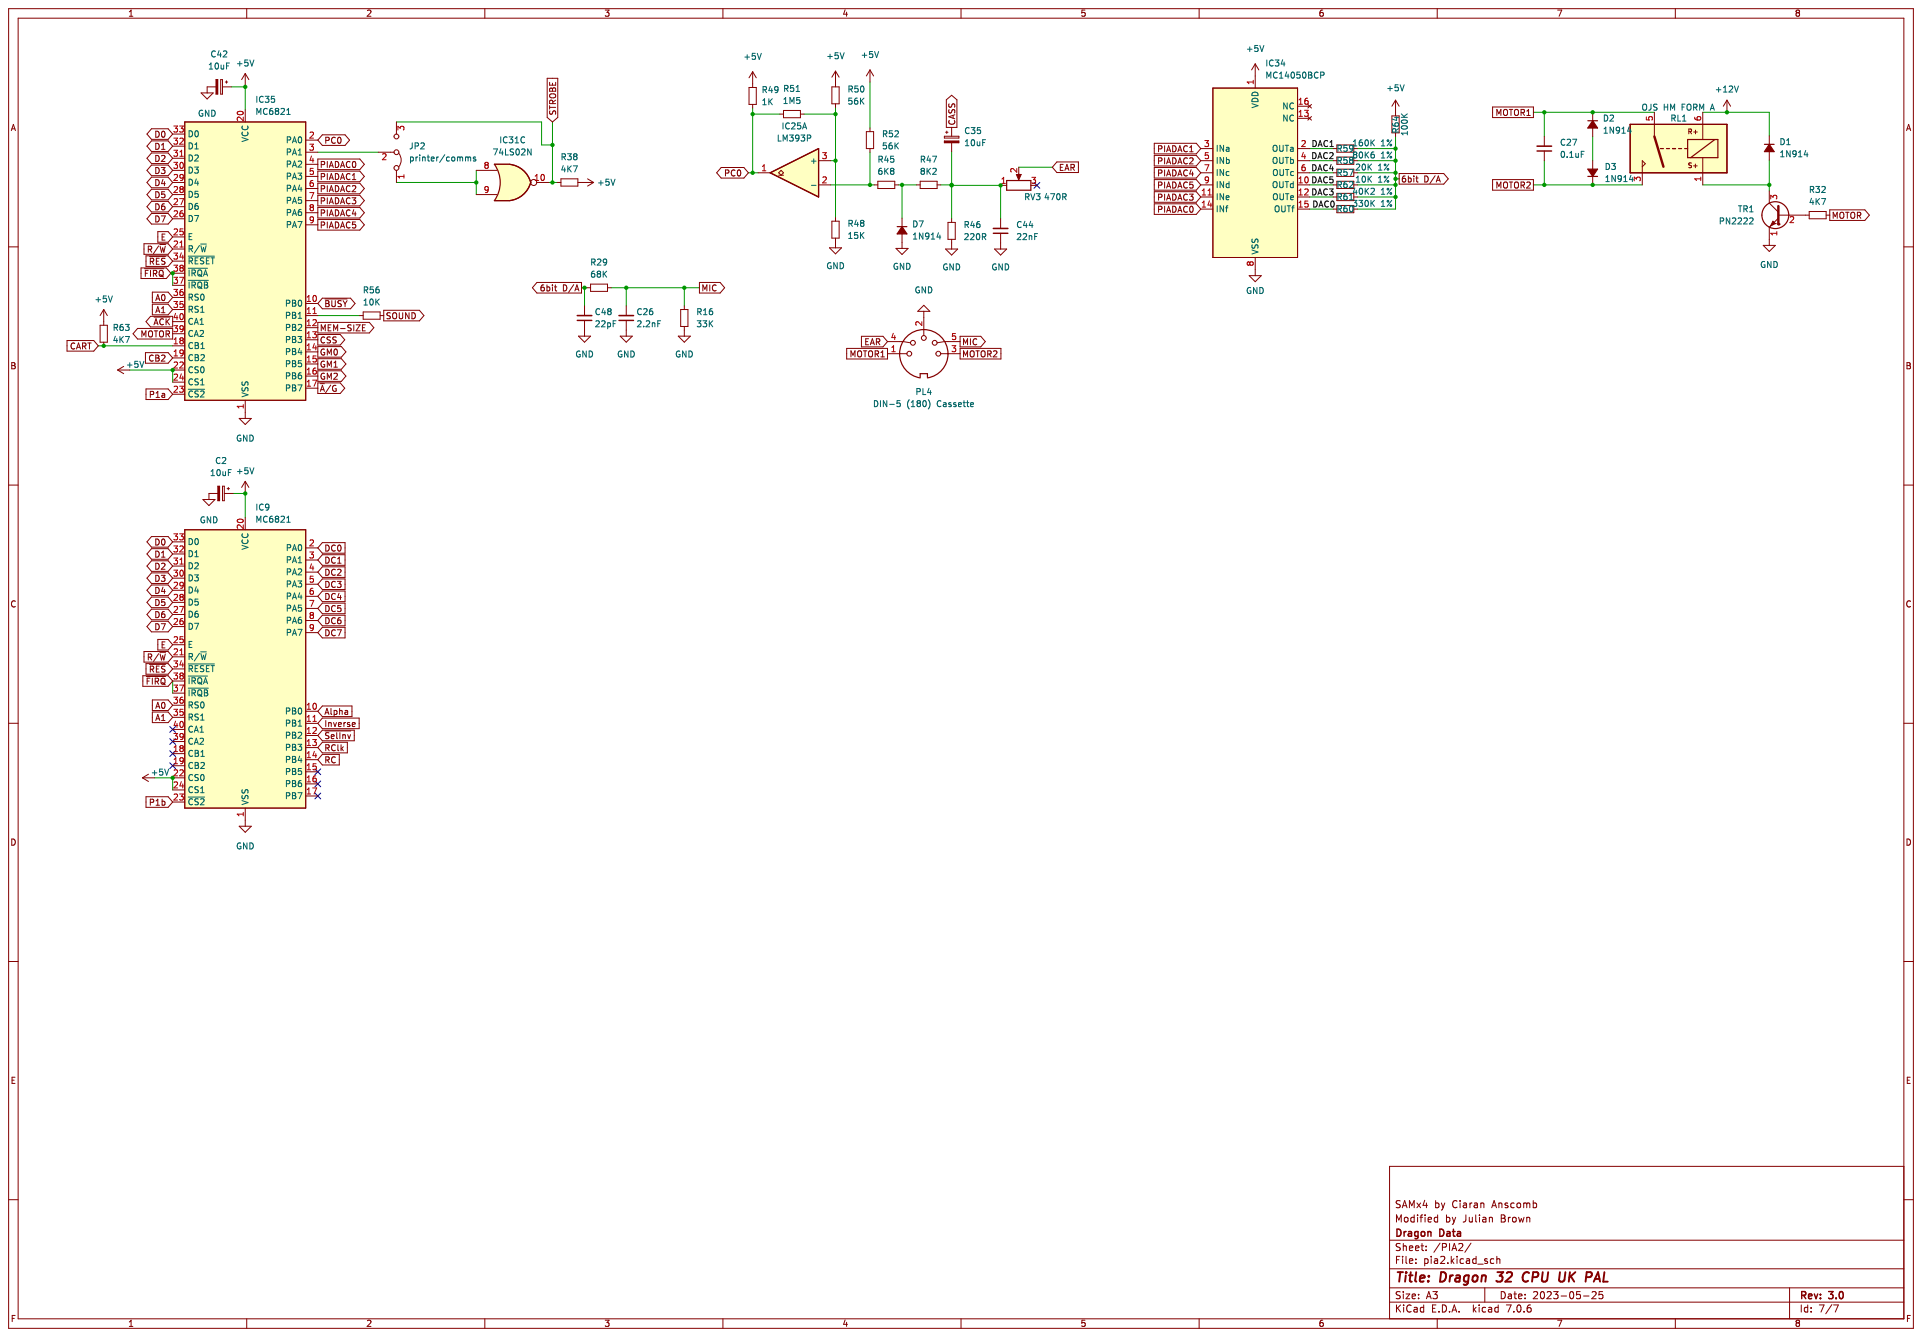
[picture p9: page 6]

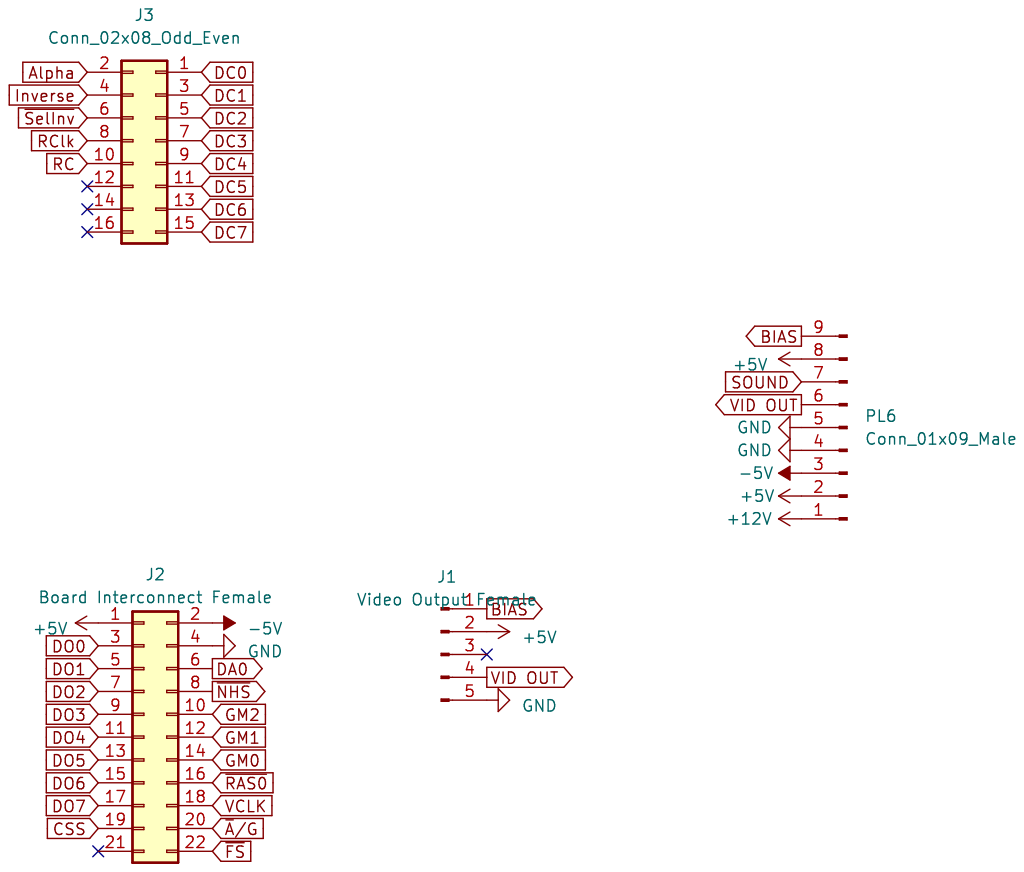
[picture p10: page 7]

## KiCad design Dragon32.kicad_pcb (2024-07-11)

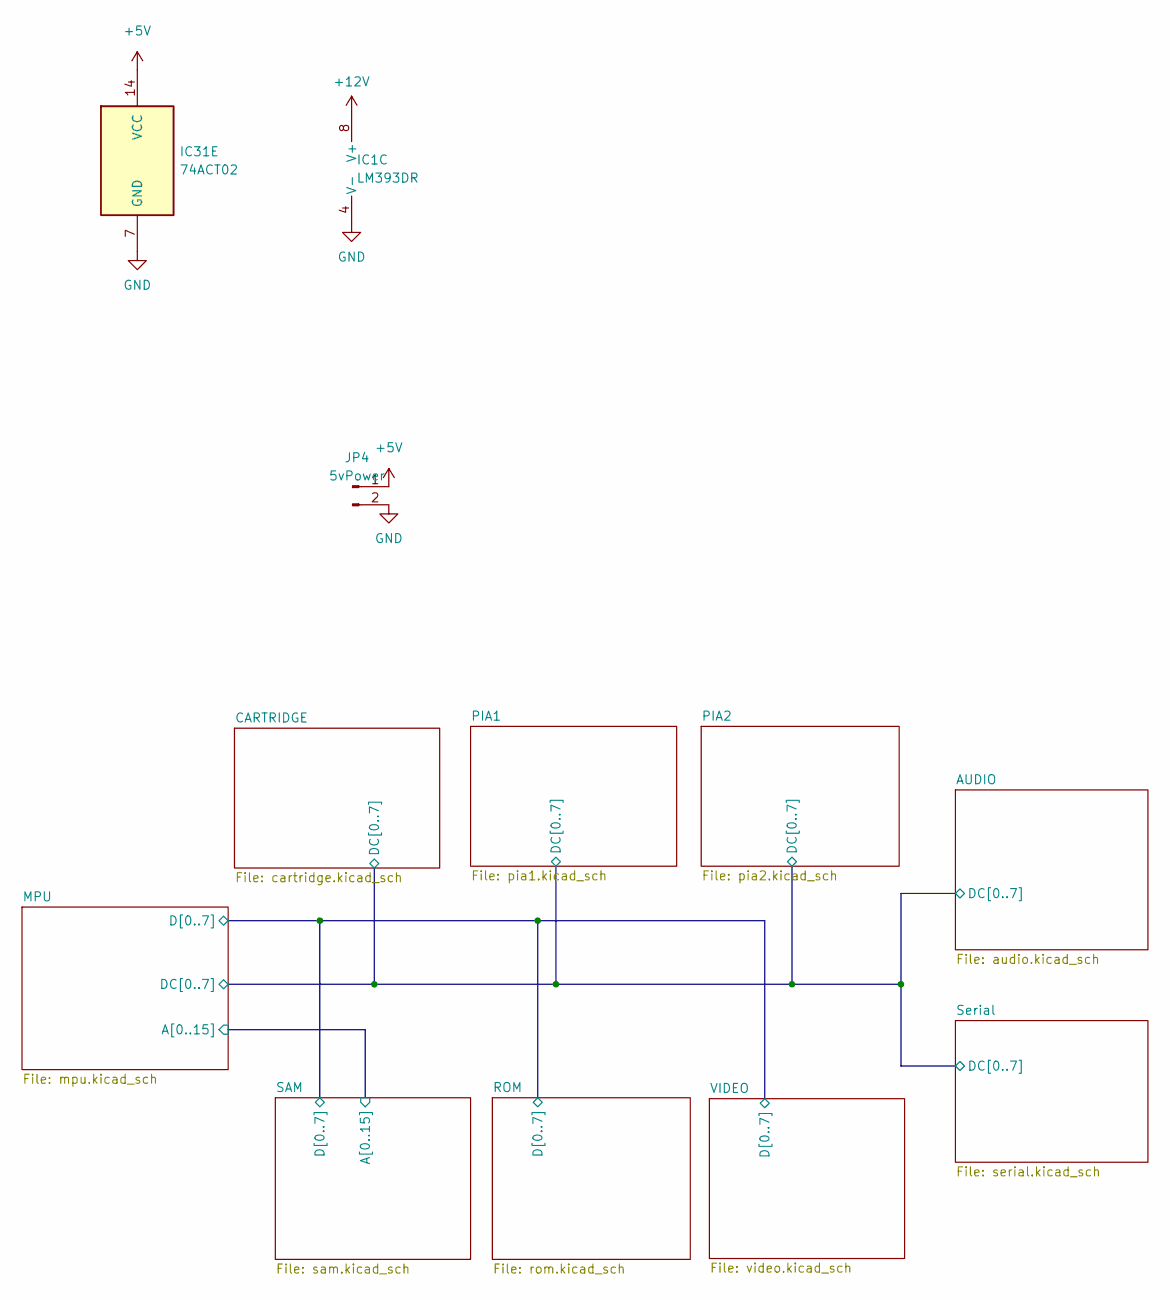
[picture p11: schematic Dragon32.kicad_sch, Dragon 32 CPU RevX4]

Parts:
IC1: LM393DR; SOP-8_3.9x4.9mm_P1.27mm; DigiKey 296-1015-1-ND
IC31: 74ACT02; SOIC-14_3.9x8.7mm_P1.27mm; DigiKey MC74ACT02DR2GOSCT-ND
JP4: 5vPower; PinHeader_1x02_P2.54mm_Vertical

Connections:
+12V: IC1.8 (V+); also elsewhere on the board

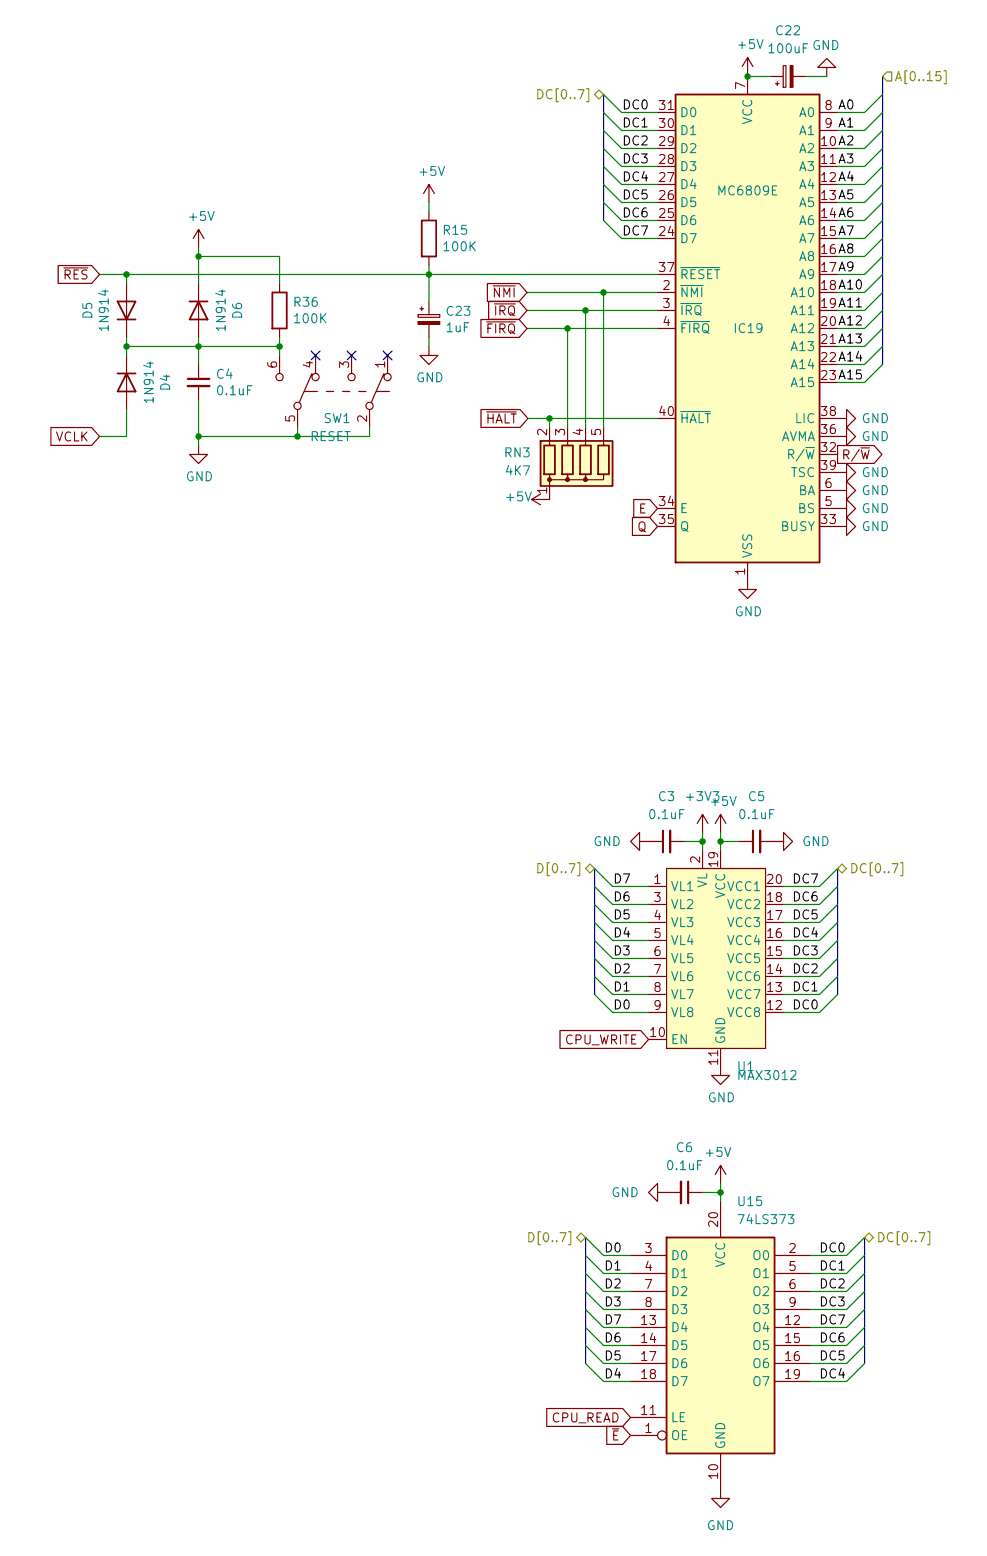
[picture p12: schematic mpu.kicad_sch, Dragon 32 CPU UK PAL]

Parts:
C3, C5, C6: 0.1uF; C_0805_2012Metric_Pad1.18x1.45mm_HandSolder; DigiKey 399-C0805C104K4RAC7800CT-ND
C4: 0.1uF; C_0805_2012Metric_Pad1.18x1.45mm_HandSolder; DigiKey BC1101CT-ND
C22: 100uF; CP_Elec_5x5.3; DigiKey 732-8598-1-ND
C23: 1uF; CP_Elec_4x4.5; DigiKey 732-8541-1-ND
D4, D5, D6: 1N914; D_SOD-323_HandSoldering; DigiKey 1N914FS-ND
IC19: MC6809E; DIP-40_W15.24mm
R15, R36: 100K; R_0805_2012Metric_Pad1.20x1.40mm_HandSolder; DigiKey CF14JT100KCT-ND
RN3: 4K7; R_Array_SIP5
SW1: RESET; Button_AlpsAlpine_SPUN190900; DigiKey 401-1225-ND
U1: MAX3012; TSSOP-20_4.4x6.5mm_P0.65mm; DigiKey MAX3012EUP+-ND
U15: 74LS373; SOIC-20W_7.5x12.8mm_P1.27mm

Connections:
/AUDIO/DC0: IC19.31 (D0), U1.12 (VCC8), U15.2 (O0); also elsewhere on the board
/AUDIO/DC1: IC19.30 (D1), U1.13 (VCC7), U15.5 (O1); also elsewhere on the board
/AUDIO/DC2: IC19.29 (D2), U1.14 (VCC6), U15.6 (O2); also elsewhere on the board
/AUDIO/DC3: IC19.28 (D3), U1.15 (VCC5), U15.9 (O3); also elsewhere on the board
/AUDIO/DC4: IC19.27 (D4), U1.16 (VCC4), U15.19 (O7); also elsewhere on the board
/AUDIO/DC5: IC19.26 (D5), U1.17 (VCC3), U15.16 (O6); also elsewhere on the board
/AUDIO/DC6: IC19.25 (D6), U1.18 (VCC2), U15.15 (O5); also elsewhere on the board
/AUDIO/DC7: IC19.24 (D7), U1.20 (VCC1), U15.12 (O4); also elsewhere on the board
/MPU/A0: IC19.8 (A0); also elsewhere on the board
/MPU/A1: IC19.9 (A1); also elsewhere on the board
/MPU/A2: IC19.10 (A2); also elsewhere on the board
/MPU/A3: IC19.11 (A3); also elsewhere on the board
/MPU/A4: IC19.12 (A4); also elsewhere on the board
/MPU/A5: IC19.13 (A5); also elsewhere on the board
/MPU/A6: IC19.14 (A6); also elsewhere on the board
/MPU/A7: IC19.15 (A7); also elsewhere on the board
/MPU/A13: IC19.21 (A13); also elsewhere on the board
/MPU/A14: IC19.22 (A14); also elsewhere on the board
/MPU/A15: IC19.23 (A15); also elsewhere on the board
/MPU/D0: U1.9 (VL8), U15.3 (D0); also elsewhere on the board
/MPU/D1: U1.8 (VL7), U15.4 (D1); also elsewhere on the board
/MPU/D2: U1.7 (VL6), U15.7 (D2); also elsewhere on the board
/MPU/D3: U1.6 (VL5), U15.8 (D3); also elsewhere on the board
/MPU/D5: U1.4 (VL3), U15.17 (D6); also elsewhere on the board
CPU_READ: U15.11 (LE); also elsewhere on the board
CPU_WRITE: U1.10 (EN); also elsewhere on the board
E: IC19.34 (E); also elsewhere on the board
unnamed: C4.1, D4.1 (K), D5.1 (K), D6.2 (A), R36.2, SW1.6 (C)
Q: IC19.35 (Q); also elsewhere on the board
R/~W: IC19.32 (R/~W); also elsewhere on the board
VCLK: D4.2 (A); also elsewhere on the board
~E: U15.1 (OE); also elsewhere on the board
~FIRQ: IC19.4 (~FIRQ), RN3.3 (R2); also elsewhere on the board
~HALT: IC19.40 (~HALT), RN3.2 (R1); also elsewhere on the board
~IRQ: IC19.3 (~IRQ), RN3.4 (R3); also elsewhere on the board
~NMI: IC19.2 (~NMI), RN3.5 (R4); also elsewhere on the board
~RES: C23.1, D5.2 (A), IC19.37 (~RESET), R15.2; also elsewhere on the board

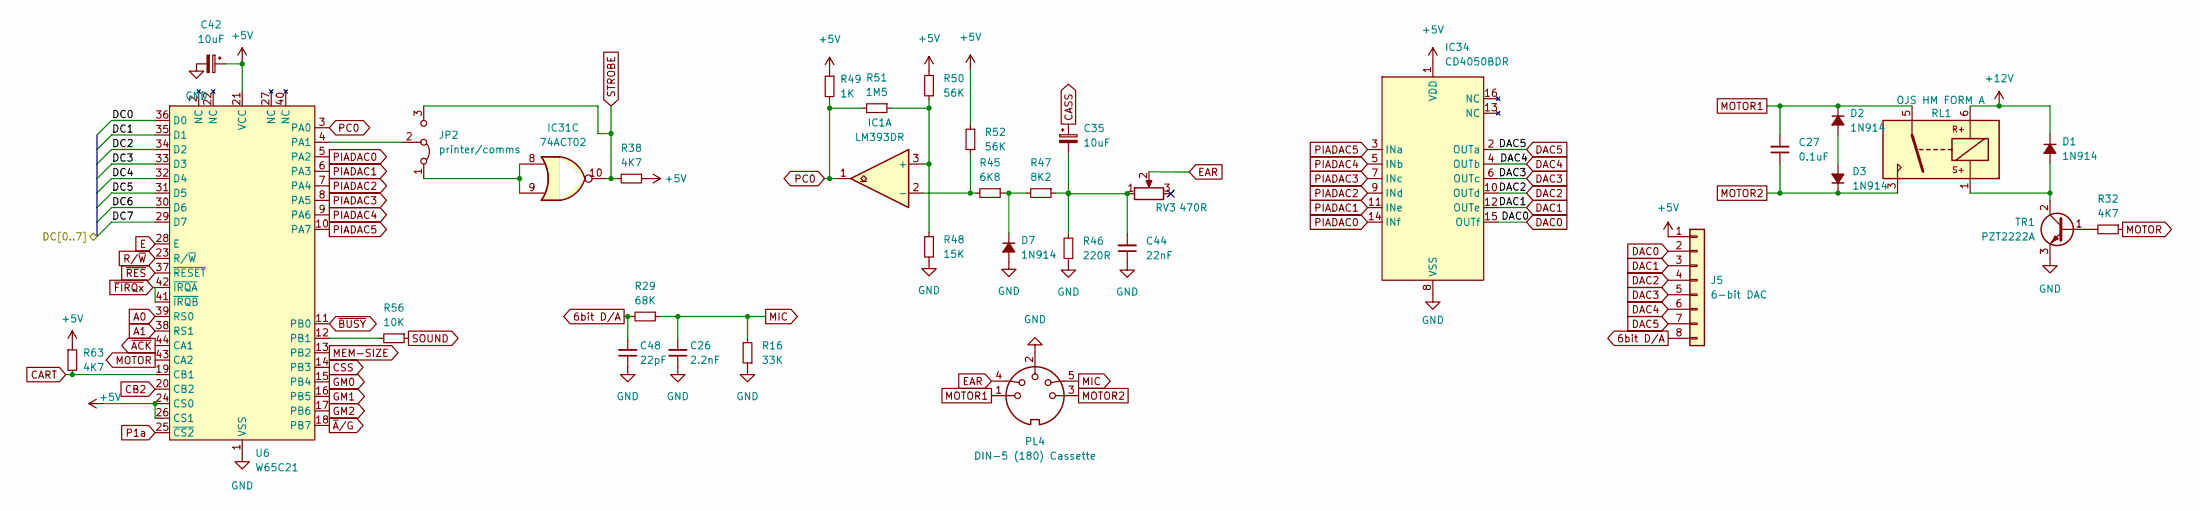
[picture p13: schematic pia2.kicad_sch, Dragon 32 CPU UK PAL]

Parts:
C26: 2.2nF; C_0805_2012Metric_Pad1.18x1.45mm_HandSolder; DigiKey BC1074CT-ND
C27: 0.1uF; C_0805_2012Metric_Pad1.18x1.45mm_HandSolder; DigiKey BC1101CT-ND
C35, C42: 10uF; CP_Elec_5x5.3; DigiKey 732-8593-1-ND
C44: 22nF; C_0805_2012Metric_Pad1.18x1.45mm_HandSolder; DigiKey BC2677CT-ND
C48: 22pF; C_0805_2012Metric_Pad1.18x1.45mm_HandSolder; DigiKey 399-13930-1-ND
D1, D2, D3, D7: 1N914; D_SOD-323_HandSoldering; DigiKey 1N914FS-ND
IC1: LM393DR; SOP-8_3.9x4.9mm_P1.27mm; DigiKey 296-1015-1-ND
IC31: 74ACT02; SOIC-14_3.9x8.7mm_P1.27mm; DigiKey MC74ACT02DR2GOSCT-ND
IC34: CD4050BDR; SOIC-16W_7.5x10.3mm_P1.27mm; DigiKey 296-31503-1-ND
J5: 6-bit DAC; PinSocket_1x08_P2.54mm_Vertical
JP2: printer/comms; PinHeader_1x03_P2.54mm_Vertical
PL4: DIN-5 (180) Cassette; DIN-5_DELTRON_671-0501_45deg_Horizontal
R16: 33K; R_0805_2012Metric_Pad1.20x1.40mm_HandSolder; DigiKey CF14JT33K0CT-ND
R29: 68K; R_0805_2012Metric_Pad1.20x1.40mm_HandSolder; DigiKey CF14JT68K0CT-ND
R32, R38, R63: 4K7; R_0805_2012Metric_Pad1.20x1.40mm_HandSolder; DigiKey CF14JT4K70CT-ND
R45: 6K8; R_0805_2012Metric_Pad1.20x1.40mm_HandSolder; DigiKey CF14JT6K80CT-ND
R46: 220R; R_0805_2012Metric_Pad1.20x1.40mm_HandSolder; DigiKey CF14JT220RCT-ND
R47: 8K2; R_0805_2012Metric_Pad1.20x1.40mm_HandSolder; DigiKey CF14JT8K20CT-ND
R48: 15K; R_0805_2012Metric_Pad1.20x1.40mm_HandSolder; DigiKey CF14JT15K0CT-ND
R49: 1K; R_0805_2012Metric_Pad1.20x1.40mm_HandSolder; DigiKey CF14JT1K00CT-ND
R50, R52: 56K; R_0805_2012Metric_Pad1.20x1.40mm_HandSolder; DigiKey CF14JT56K0CT-ND
R51: 1M5; R_0805_2012Metric_Pad1.20x1.40mm_HandSolder; DigiKey CF14JT1M50CT-ND
R56: 10K; R_0805_2012Metric_Pad1.20x1.40mm_HandSolder; DigiKey CF14JT10K0CT-ND
RL1: OJS HM FORM A; OJS HM 10A Relay; DigiKey 41-OJS-SH-105HMF,00000-ND
RV3: 470R; Potentiometer_Bourns_3386X_Horizontal; DigiKey 3386H-103LF-ND
TR1: PZT2222A; SOT-223-3_TabPin2
U6: W65C21; PLCC-44_SMD-Socket

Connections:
+12V: D1.1 (K), RL1.6; also elsewhere on the board
/AUDIO/DC0: U6.36 (D0); also elsewhere on the board
/AUDIO/DC1: U6.35 (D1); also elsewhere on the board
/AUDIO/DC2: U6.34 (D2); also elsewhere on the board
/AUDIO/DC3: U6.33 (D3); also elsewhere on the board
/AUDIO/DC4: U6.32 (D4); also elsewhere on the board
/AUDIO/DC5: U6.31 (D5); also elsewhere on the board
/AUDIO/DC6: U6.30 (D6); also elsewhere on the board
/AUDIO/DC7: U6.29 (D7); also elsewhere on the board
A0: U6.39 (RS0); also elsewhere on the board
A1: U6.38 (RS1); also elsewhere on the board
CART: R63.2, U6.19 (CB1); also elsewhere on the board
CB2: U6.20 (CB2); also elsewhere on the board
CSS: U6.14 (PB3); also elsewhere on the board
DAC0: IC34.15 (OUTf), J5.2
DAC1: IC34.12 (OUTe), J5.3
DAC2: IC34.10 (OUTd), J5.4
DAC3: IC34.6 (OUTc), J5.5
DAC4: IC34.4 (OUTb), J5.6
DAC5: IC34.2 (OUTa), J5.7
E: U6.28 (E); also elsewhere on the board
EAR: PL4.4, RV3.2
GM0: U6.15 (PB4); also elsewhere on the board
GM1: U6.16 (PB5); also elsewhere on the board
GM2: U6.17 (PB6); also elsewhere on the board
MEM-SIZE: U6.13 (PB2)
MIC: C26.2, PL4.5, R16.2, R29.1
MOTOR: R32.1, U6.43 (CA2)
MOTOR1: C27.2, D2.1 (K), PL4.1, RL1.5
MOTOR2: C27.1, D3.1 (K), PL4.3, RL1.3
unnamed: C35.2, C44.2, R46.2, R47.1, RV3.1
unnamed: D1.2 (A), RL1.1, TR1.2 (C)
unnamed: D2.2 (A), D3.2 (A)
unnamed: D7.1 (K), R45.1, R47.2
unnamed: IC1.3 (+), R48.2, R50.1, R51.1
unnamed: IC1.2 (-), R45.2, R52.1
unnamed: IC31.8, IC31.9, JP2.1 (A)
unnamed: JP2.2 (C), U6.4 (PA1)
unnamed: R32.2, TR1.1 (B)
unnamed: R56.2, U6.12 (PB1)
OUT_L: R56.1; also elsewhere on the board
P1a: U6.25 (~CS2); also elsewhere on the board
PC0: IC1.1, R49.2, R51.2, U6.3 (PA0)
PIADAC0: IC34.14 (INf), U6.5 (PA2)
PIADAC1: IC34.11 (INe), U6.6 (PA3)
PIADAC2: IC34.9 (INd), U6.7 (PA4)
PIADAC3: IC34.7 (INc), U6.8 (PA5)
PIADAC4: IC34.5 (INb), U6.9 (PA6)
PIADAC5: IC34.3 (INa), U6.10 (PA7)
R/~W: U6.23 (R/~W); also elsewhere on the board
STROBE: IC31.10, JP2.3 (B), R38.2; also elsewhere on the board
~ACK: U6.44 (CA1); also elsewhere on the board
~A/G: U6.18 (PB7); also elsewhere on the board
~BUSY: U6.11 (PB0); also elsewhere on the board
~FIRQx: U6.41 (~IRQB), U6.42 (~IRQA); also elsewhere on the board
~RES: U6.37 (~RESET); also elsewhere on the board

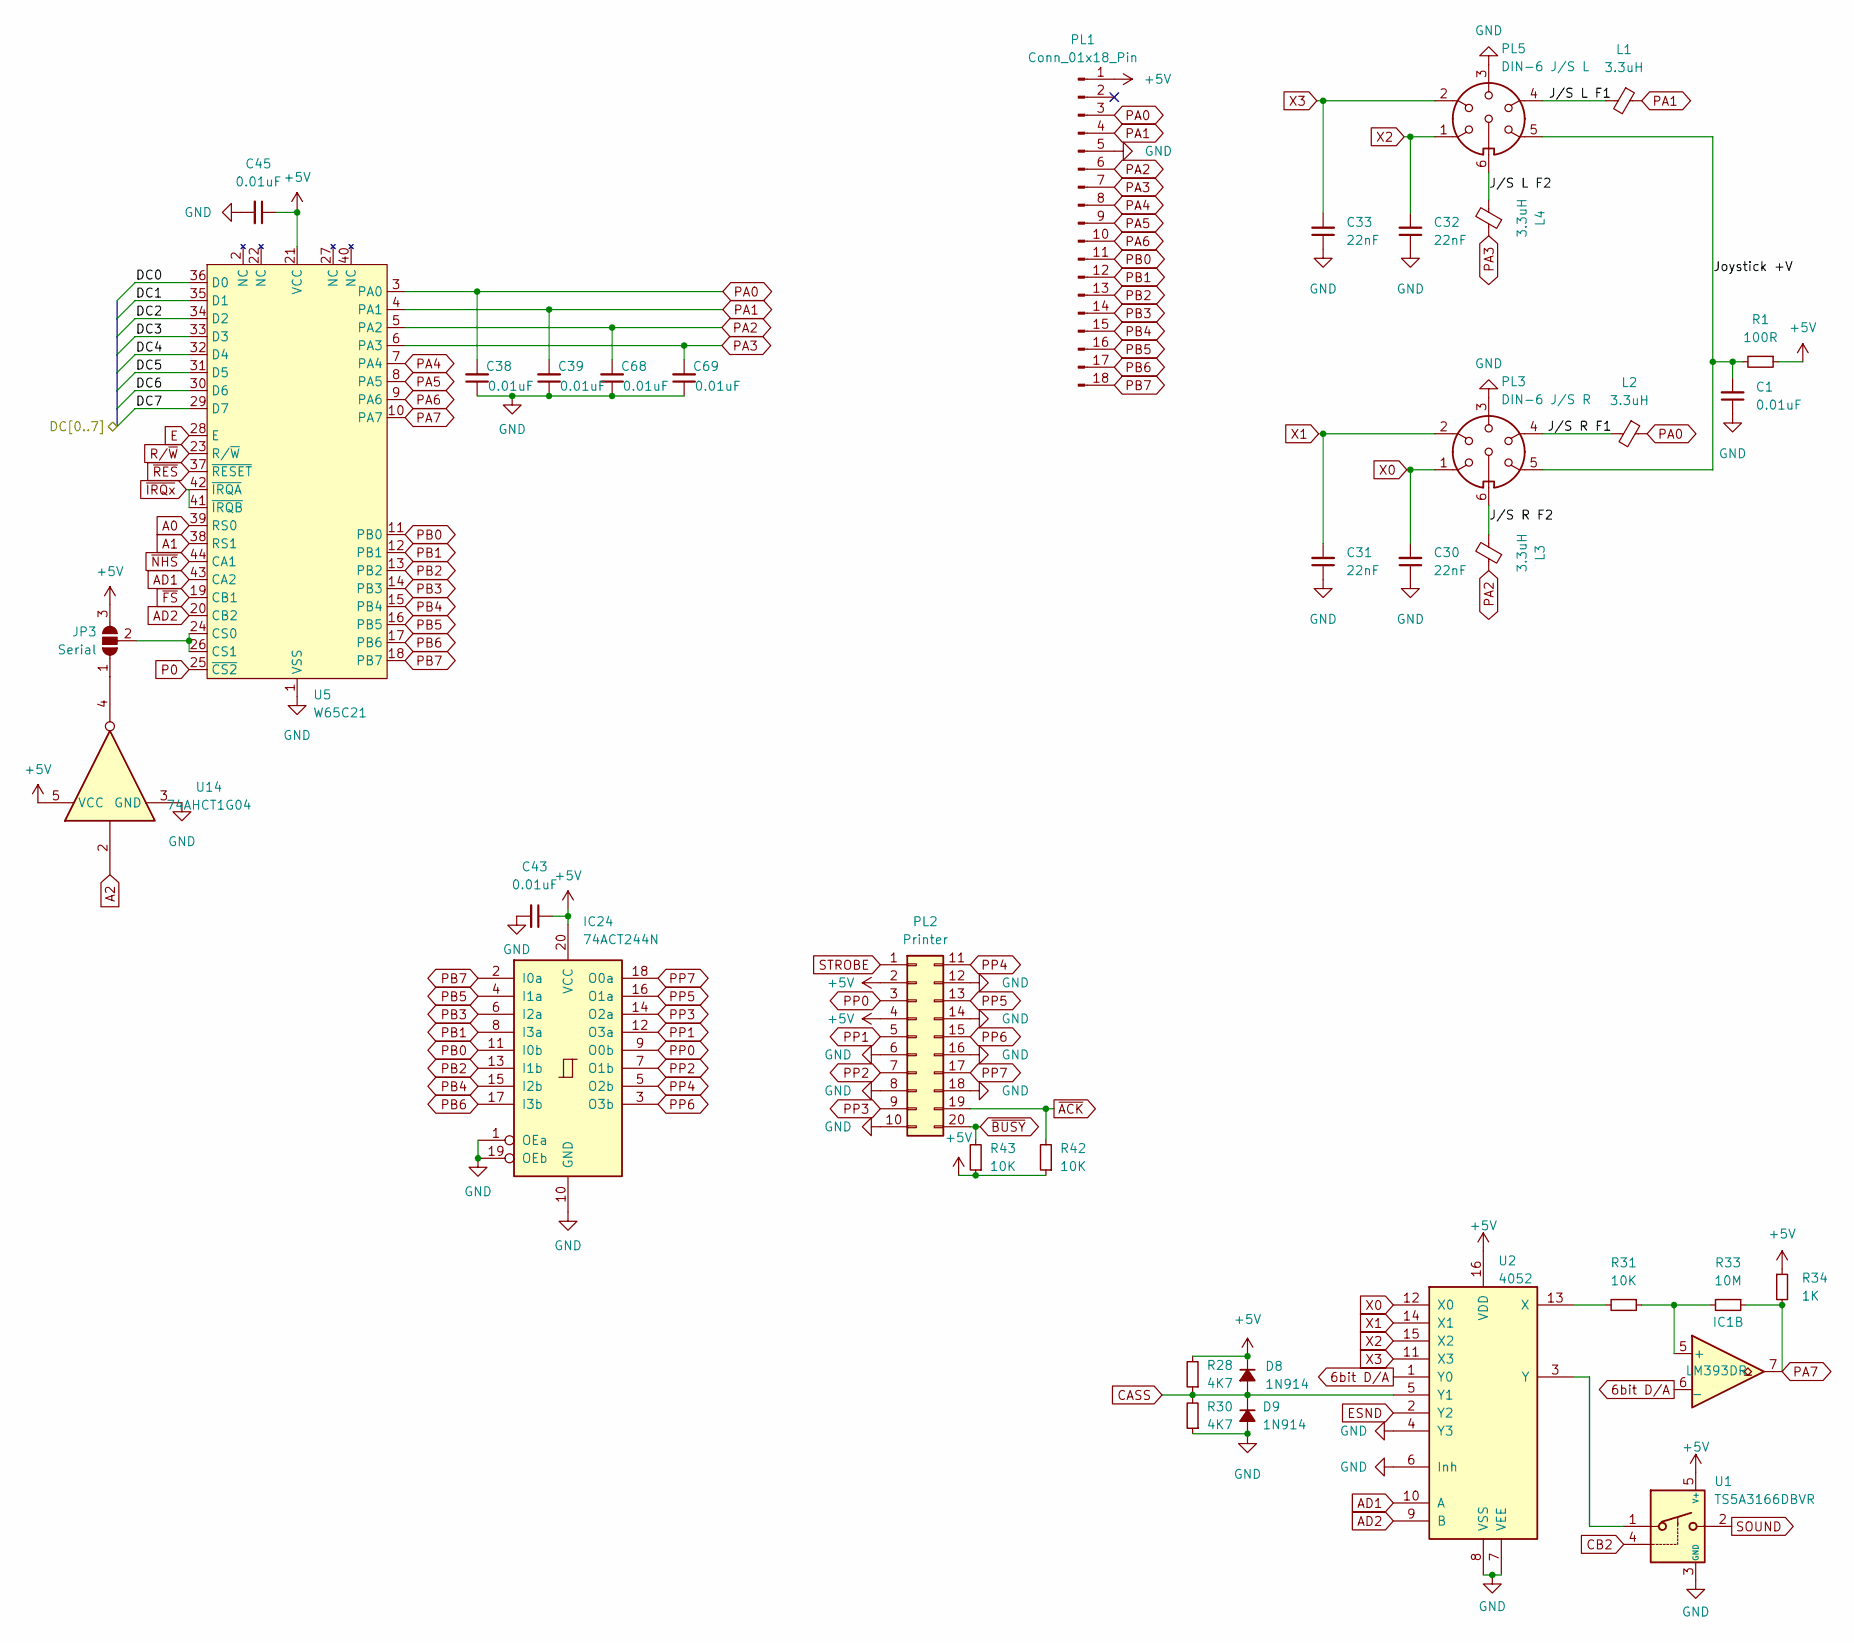
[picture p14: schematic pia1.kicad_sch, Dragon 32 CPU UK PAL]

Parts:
C1, C43, C45: 0.01uF; C_0805_2012Metric_Pad1.18x1.45mm_HandSolder; DigiKey BC2662CT-ND
C30, C31, C32, C33: 22nF; C_0805_2012Metric_Pad1.18x1.45mm_HandSolder; DigiKey BC2677CT-ND
C38, C39, C68, C69: 0.01uF; C_0805_2012Metric_Pad1.18x1.45mm_HandSolder; DigiKey BC1101CT-ND
D8, D9: 1N914; D_SOD-323_HandSoldering; DigiKey 1N914FS-ND
IC1: LM393DR; SOP-8_3.9x4.9mm_P1.27mm; DigiKey 296-1015-1-ND
IC24: 74ACT244N; SOIC-20W_7.5x12.8mm_P1.27mm; DigiKey 74ACT244SCXCT-ND
JP3: Serial; SolderJumper-3_P1.3mm_Open_Pad1.0x1.5mm
L1, L2, L3, L4: 3.3uH; L_1812_4532Metric_Pad1.30x3.40mm_HandSolder; DigiKey 495-5561-1-ND
PL1: Conn_01x18_Pin; PinHeader_1x18_P2.54mm_Vertical
PL2: Printer; IDC-Header_2x10-1MP_P2.54mm_Latch_Horizontal; DigiKey CHR20G-ND
PL3: DIN-6 J/S R; DIN-6_DELTRON_671-0601_Horizontal
PL5: DIN-6 J/S L; DIN-6_DELTRON_671-0601_Horizontal
R1: 100R; R_0805_2012Metric_Pad1.20x1.40mm_HandSolder; DigiKey CF14JT100RCT-ND
R28, R30: 4K7; R_0805_2012Metric_Pad1.20x1.40mm_HandSolder; DigiKey CF14JT4K70CT-ND
R31, R42, R43: 10K; R_0805_2012Metric_Pad1.20x1.40mm_HandSolder; DigiKey CF14JT10K0CT-ND
R33: 10M; R_0805_2012Metric_Pad1.20x1.40mm_HandSolder; DigiKey CF14JT10M0CT-ND
R34: 1K; R_0805_2012Metric_Pad1.20x1.40mm_HandSolder; DigiKey CF14JT1K00CT-ND
U1: TS5A3166DBVR; SOT-23-5
U2: 4052; TSSOP-16_4.4x5mm_P0.65mm
U5: W65C21; PLCC-44_SMD-Socket
U14: 74AHCT1G04; SOT-23-5_HandSoldering

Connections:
/AUDIO/DC0: U5.36 (D0); also elsewhere on the board
/AUDIO/DC1: U5.35 (D1); also elsewhere on the board
/AUDIO/DC2: U5.34 (D2); also elsewhere on the board
/AUDIO/DC3: U5.33 (D3); also elsewhere on the board
/AUDIO/DC4: U5.32 (D4); also elsewhere on the board
/AUDIO/DC5: U5.31 (D5); also elsewhere on the board
/AUDIO/DC6: U5.30 (D6); also elsewhere on the board
/AUDIO/DC7: U5.29 (D7); also elsewhere on the board
/MPU/D5: U1.4 (VL3); also elsewhere on the board
/PIA1/Joystick +V: C1.2, PL3.5, PL5.5, R1.2
/PIA1/J/S L F1: L1.2, PL5.4
/PIA1/J/S L F2: L4.2, PL5.6
/PIA1/J/S R F1: L2.2, PL3.4
/PIA1/J/S R F2: L3.2, PL3.6
A0: U5.39 (RS0); also elsewhere on the board
A1: U5.38 (RS1); also elsewhere on the board
A2: U14.2
E: U5.28 (E); also elsewhere on the board
unnamed: IC1.5 (+), R31.1, R33.2
unnamed: JP3.1 (A), U14.4
unnamed: JP3.2 (C), U5.24 (CS0), U5.26 (CS1)
P0: U5.25 (~CS2); also elsewhere on the board
PA0: C38.2, L2.1, PL1.3, U5.3 (PA0)
PA1: C39.2, L1.1, PL1.4, U5.4 (PA1)
PA2: C68.2, L3.1, PL1.6, U5.5 (PA2)
PA3: C69.2, L4.1, PL1.7, U5.6 (PA3)
PA4: PL1.8, U5.7 (PA4)
PA5: PL1.9, U5.8 (PA5)
PA6: PL1.10, U5.9 (PA6)
PA7: IC1.7, R33.1, R34.2, U5.10 (PA7)
PB0: IC24.11 (I0b), PL1.11, U5.11 (PB0)
PB1: IC24.8 (I3a), PL1.12, U5.12 (PB1)
PB2: IC24.13 (I1b), PL1.13, U5.13 (PB2)
PB3: IC24.6 (I2a), PL1.14, U5.14 (PB3)
PB4: IC24.15 (I2b), PL1.15, U5.15 (PB4)
PB5: IC24.4 (I1a), PL1.16, U5.16 (PB5)
PB6: IC24.17 (I3b), PL1.17, U5.17 (PB6)
PB7: IC24.2 (I0a), PL1.18, U5.18 (PB7)
PP0: IC24.9 (O0b), PL2.3
PP1: IC24.12 (O3a), PL2.5
PP2: IC24.7 (O1b), PL2.7
PP3: IC24.14 (O2a), PL2.9
PP4: IC24.5 (O2b), PL2.11
PP5: IC24.16 (O1a), PL2.13
PP6: IC24.3 (O3b), PL2.15
PP7: IC24.18 (O0a), PL2.17
R/~W: U5.23 (R/~W); also elsewhere on the board
STROBE: PL2.1; also elsewhere on the board
~ACK: PL2.19, R42.2; also elsewhere on the board
~BUSY: PL2.20, R43.2; also elsewhere on the board
~FS: U5.19 (CB1); also elsewhere on the board
~IRQx: U5.41 (~IRQB), U5.42 (~IRQA); also elsewhere on the board
~NHS: U5.44 (CA1); also elsewhere on the board
~RES: U5.37 (~RESET); also elsewhere on the board

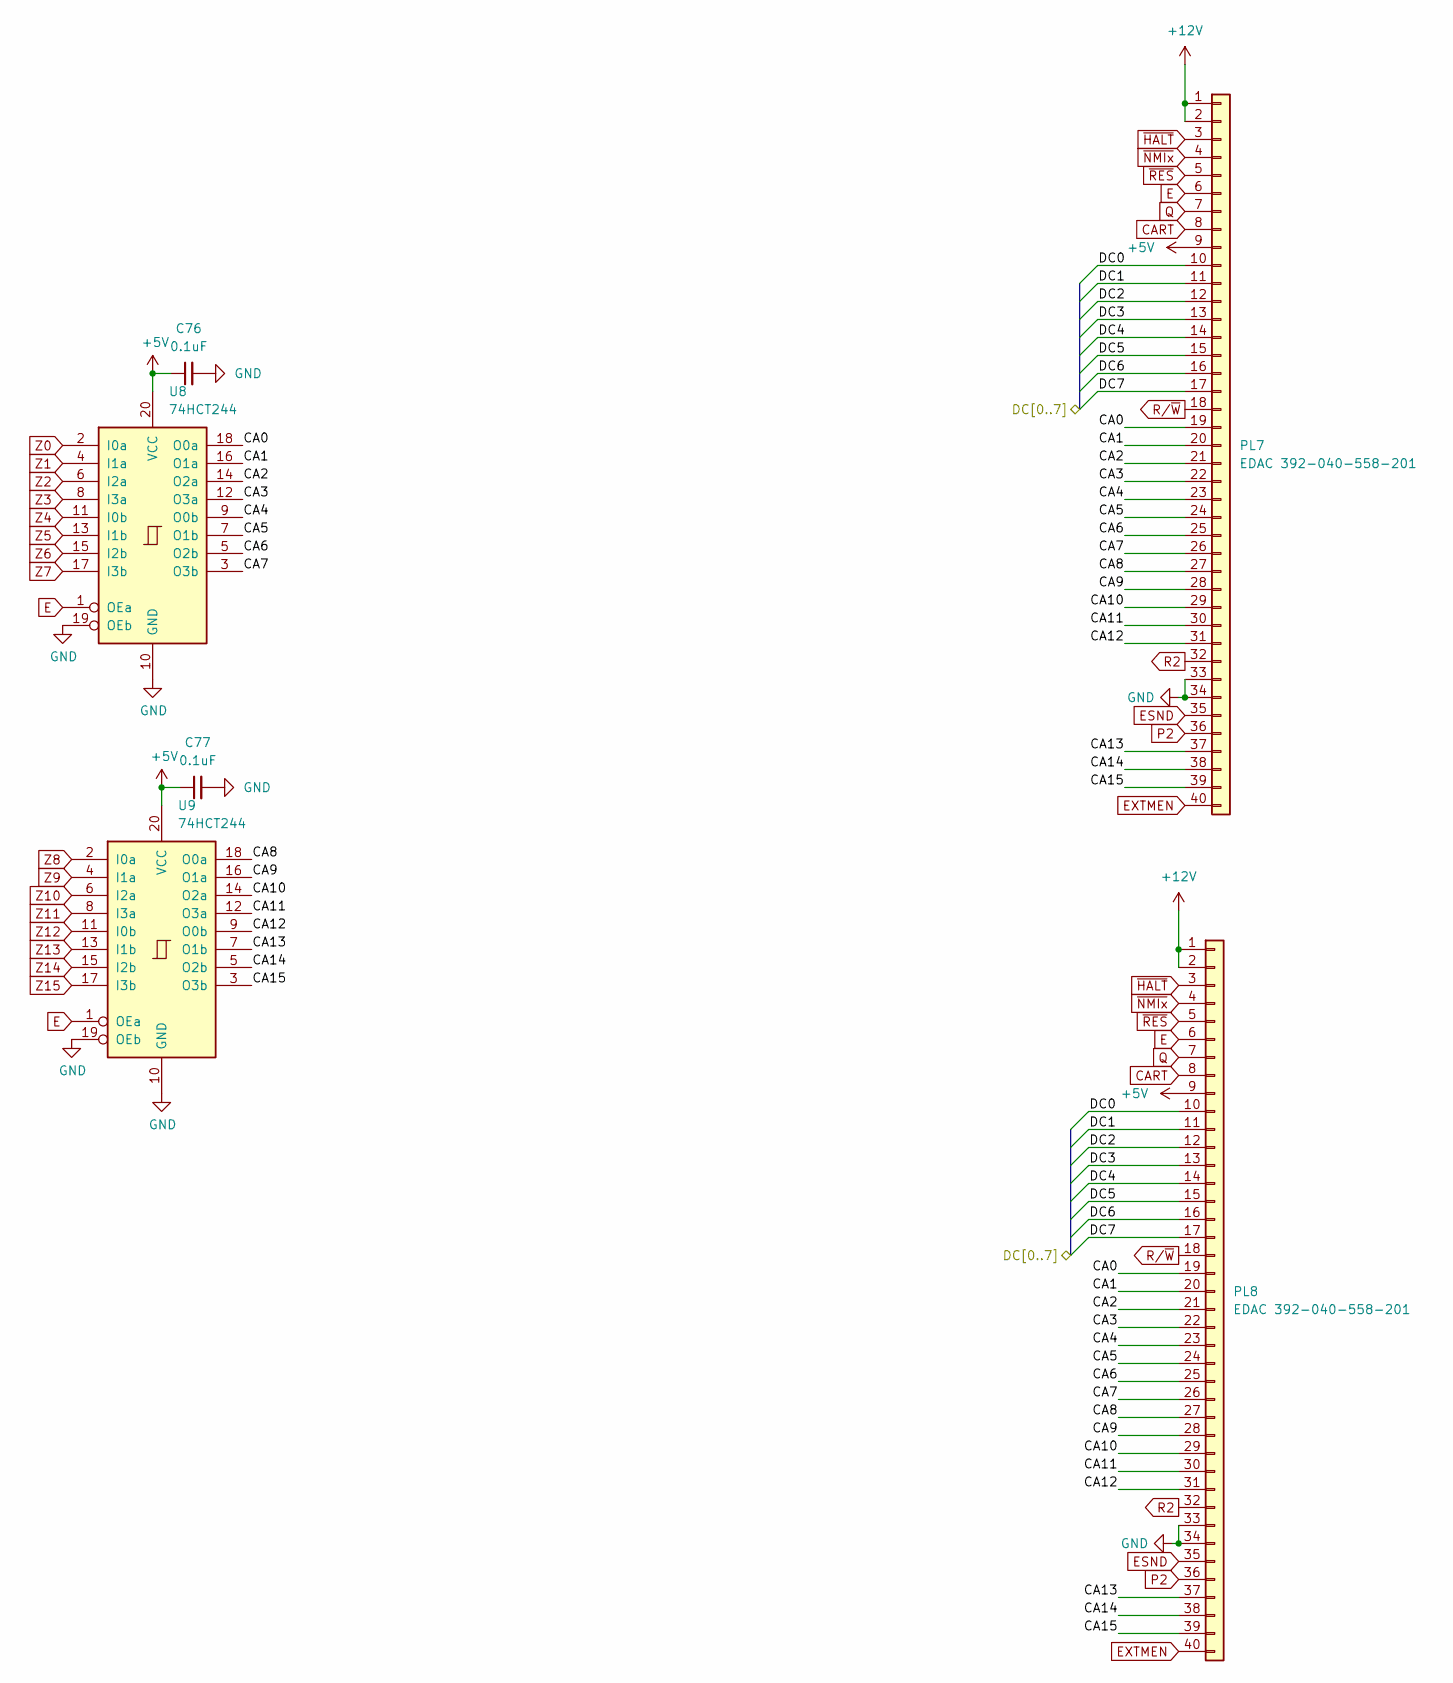
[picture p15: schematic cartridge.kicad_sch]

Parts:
C76, C77: 0.1uF; C_0805_2012Metric_Pad1.18x1.45mm_HandSolder; DigiKey 399-C0805C104K4RAC7800CT-ND
PL7: EDAC 392-040-558-201; PinHeader_2x20_P2.54mm_Vertical; DigiKey 151-395-040-558-201-ND
PL8: EDAC 392-040-558-201; Edge_2x20_P2.54mm_OvalMP; DigiKey 151-395-040-558-201-ND
U8, U9: 74HCT244; TSSOP-20_4.4x6.5mm_P0.65mm; DigiKey 296-8402-1-ND

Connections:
+12V: PL7.1, PL7.2, PL8.1, PL8.2; also elsewhere on the board
/AUDIO/DC0: PL7.10, PL8.10; also elsewhere on the board
/AUDIO/DC1: PL7.11, PL8.11; also elsewhere on the board
/AUDIO/DC2: PL7.12, PL8.12; also elsewhere on the board
/AUDIO/DC3: PL7.13, PL8.13; also elsewhere on the board
/AUDIO/DC4: PL7.14, PL8.14; also elsewhere on the board
/AUDIO/DC5: PL7.15, PL8.15; also elsewhere on the board
/AUDIO/DC6: PL7.16, PL8.16; also elsewhere on the board
/AUDIO/DC7: PL7.17, PL8.17; also elsewhere on the board
/CARTRIDGE/CA0: PL7.19, PL8.19, U8.18 (O0a)
/CARTRIDGE/CA1: PL7.20, PL8.20, U8.16 (O1a)
/CARTRIDGE/CA2: PL7.21, PL8.21, U8.14 (O2a)
/CARTRIDGE/CA3: PL7.22, PL8.22, U8.12 (O3a)
/CARTRIDGE/CA4: PL7.23, PL8.23, U8.9 (O0b)
/CARTRIDGE/CA5: PL7.24, PL8.24, U8.7 (O1b)
/CARTRIDGE/CA6: PL7.25, PL8.25, U8.5 (O2b)
/CARTRIDGE/CA7: PL7.26, PL8.26, U8.3 (O3b)
/CARTRIDGE/CA8: PL7.27, PL8.27, U9.18 (O0a)
/CARTRIDGE/CA9: PL7.28, PL8.28, U9.16 (O1a)
/CARTRIDGE/CA10: PL7.29, PL8.29, U9.14 (O2a)
/CARTRIDGE/CA11: PL7.30, PL8.30, U9.12 (O3a)
/CARTRIDGE/CA12: PL7.31, PL8.31, U9.9 (O0b)
/CARTRIDGE/CA13: PL7.37, PL8.37, U9.7 (O1b)
/CARTRIDGE/CA14: PL7.38, PL8.38, U9.5 (O2b)
/CARTRIDGE/CA15: PL7.39, PL8.39, U9.3 (O3b)
CART: PL7.8, PL8.8; also elsewhere on the board
E: PL7.6, PL8.6, U8.1 (OEa), U9.1 (OEa); also elsewhere on the board
ESND: PL7.35, PL8.35; also elsewhere on the board
EXTMEN: PL7.40, PL8.40; also elsewhere on the board
P2: PL7.36, PL8.36; also elsewhere on the board
Q: PL7.7, PL8.7; also elsewhere on the board
R2: PL7.32, PL8.32; also elsewhere on the board
R/~W: PL7.18, PL8.18; also elsewhere on the board
Z0: U8.2 (I0a); also elsewhere on the board
Z1: U8.4 (I1a); also elsewhere on the board
Z2: U8.6 (I2a); also elsewhere on the board
Z3: U8.8 (I3a); also elsewhere on the board
Z4: U8.11 (I0b); also elsewhere on the board
Z5: U8.13 (I1b); also elsewhere on the board
Z6: U8.15 (I2b); also elsewhere on the board
Z7: U8.17 (I3b); also elsewhere on the board
Z8: U9.2 (I0a); also elsewhere on the board
Z9: U9.4 (I1a); also elsewhere on the board
Z10: U9.6 (I2a); also elsewhere on the board
Z11: U9.8 (I3a); also elsewhere on the board
Z12: U9.11 (I0b); also elsewhere on the board
Z13: U9.13 (I1b); also elsewhere on the board
Z14: U9.15 (I2b); also elsewhere on the board
Z15: U9.17 (I3b); also elsewhere on the board
~HALT: PL7.3, PL8.3; also elsewhere on the board
~NMIx: PL7.4, PL8.4; also elsewhere on the board
~RES: PL7.5, PL8.5; also elsewhere on the board

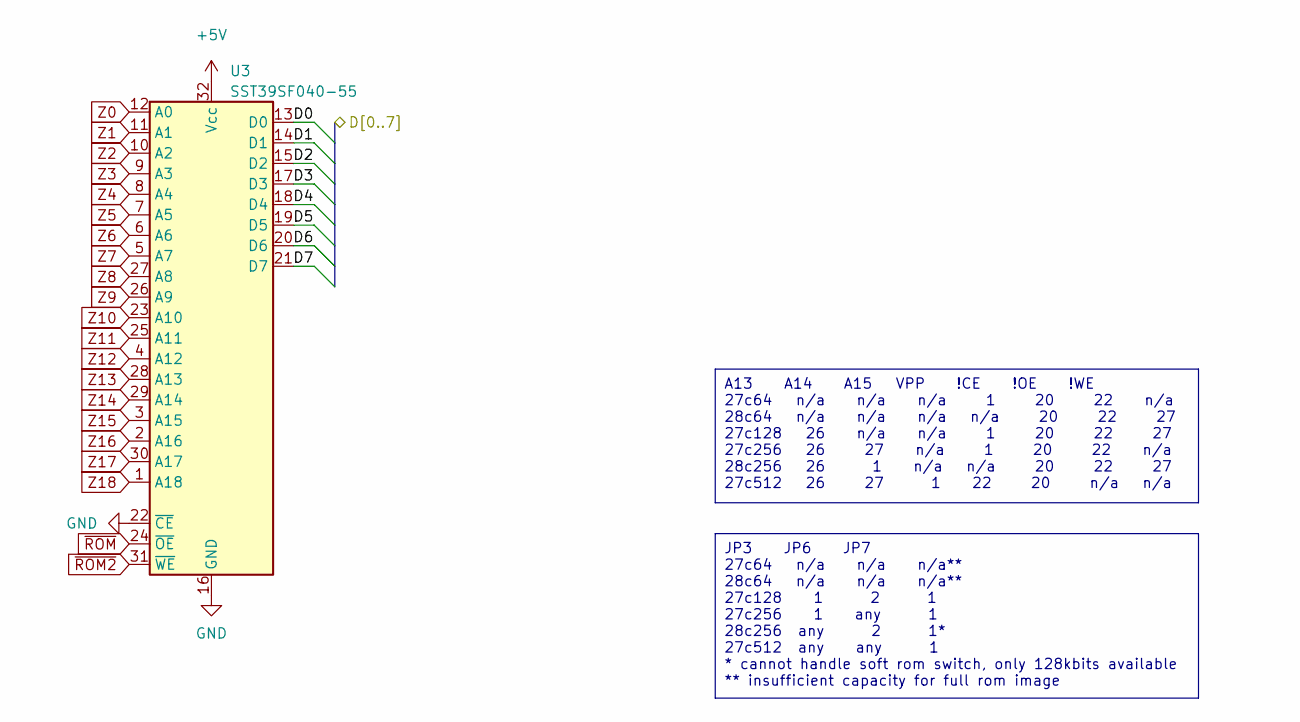
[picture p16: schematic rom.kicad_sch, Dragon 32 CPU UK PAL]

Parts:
U3: SST39SF040-55; PLCC-32_THT-Socket; DigiKey SST39SF040-55-4C-NHE-ND

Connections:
/MPU/D0: U3.13 (D0); also elsewhere on the board
/MPU/D1: U3.14 (D1); also elsewhere on the board
/MPU/D2: U3.15 (D2); also elsewhere on the board
/MPU/D3: U3.17 (D3); also elsewhere on the board
/MPU/D5: U3.19 (D5); also elsewhere on the board
Z0: U3.12 (A0); also elsewhere on the board
Z1: U3.11 (A1); also elsewhere on the board
Z2: U3.10 (A2); also elsewhere on the board
Z3: U3.9 (A3); also elsewhere on the board
Z4: U3.8 (A4); also elsewhere on the board
Z5: U3.7 (A5); also elsewhere on the board
Z6: U3.6 (A6); also elsewhere on the board
Z7: U3.5 (A7); also elsewhere on the board
Z8: U3.27 (A8); also elsewhere on the board
Z9: U3.26 (A9); also elsewhere on the board
Z10: U3.23 (A10); also elsewhere on the board
Z11: U3.25 (A11); also elsewhere on the board
Z12: U3.4 (A12); also elsewhere on the board
Z13: U3.28 (A13); also elsewhere on the board
Z14: U3.29 (A14); also elsewhere on the board
Z15: U3.3 (A15); also elsewhere on the board
Z16: U3.2 (A16); also elsewhere on the board
Z17: U3.30 (A17); also elsewhere on the board
Z18: U3.1 (A18); also elsewhere on the board
~ROM2: U3.31 (~WE)
~ROM: U3.24 (~OE)

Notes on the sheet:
JP3 JP6 JP7 27c64 n/a n/a n/a** 28c64 n/a n/a n/a** 27c128 1 2 1 27c256 1 any 1 28c256 any 2 1* 27c512 any any 1 * cannot handle soft rom switch, only 128kbits available ** insufficient capacity for full rom image
A13 A14 A15 VPP !CE !OE !WE 27c64 n/a n/a n/a 1 20 22 n/a 28c64 n/a n/a n/a n/a 20 22 27 27c128 26 n/a n/a 1 20 22 27 27c256 26 27 n/a 1 20 22 n/a 28c256 26 1 n/a n/a 20 22 27 27c512 26 27 1 22 20 n/a n/a

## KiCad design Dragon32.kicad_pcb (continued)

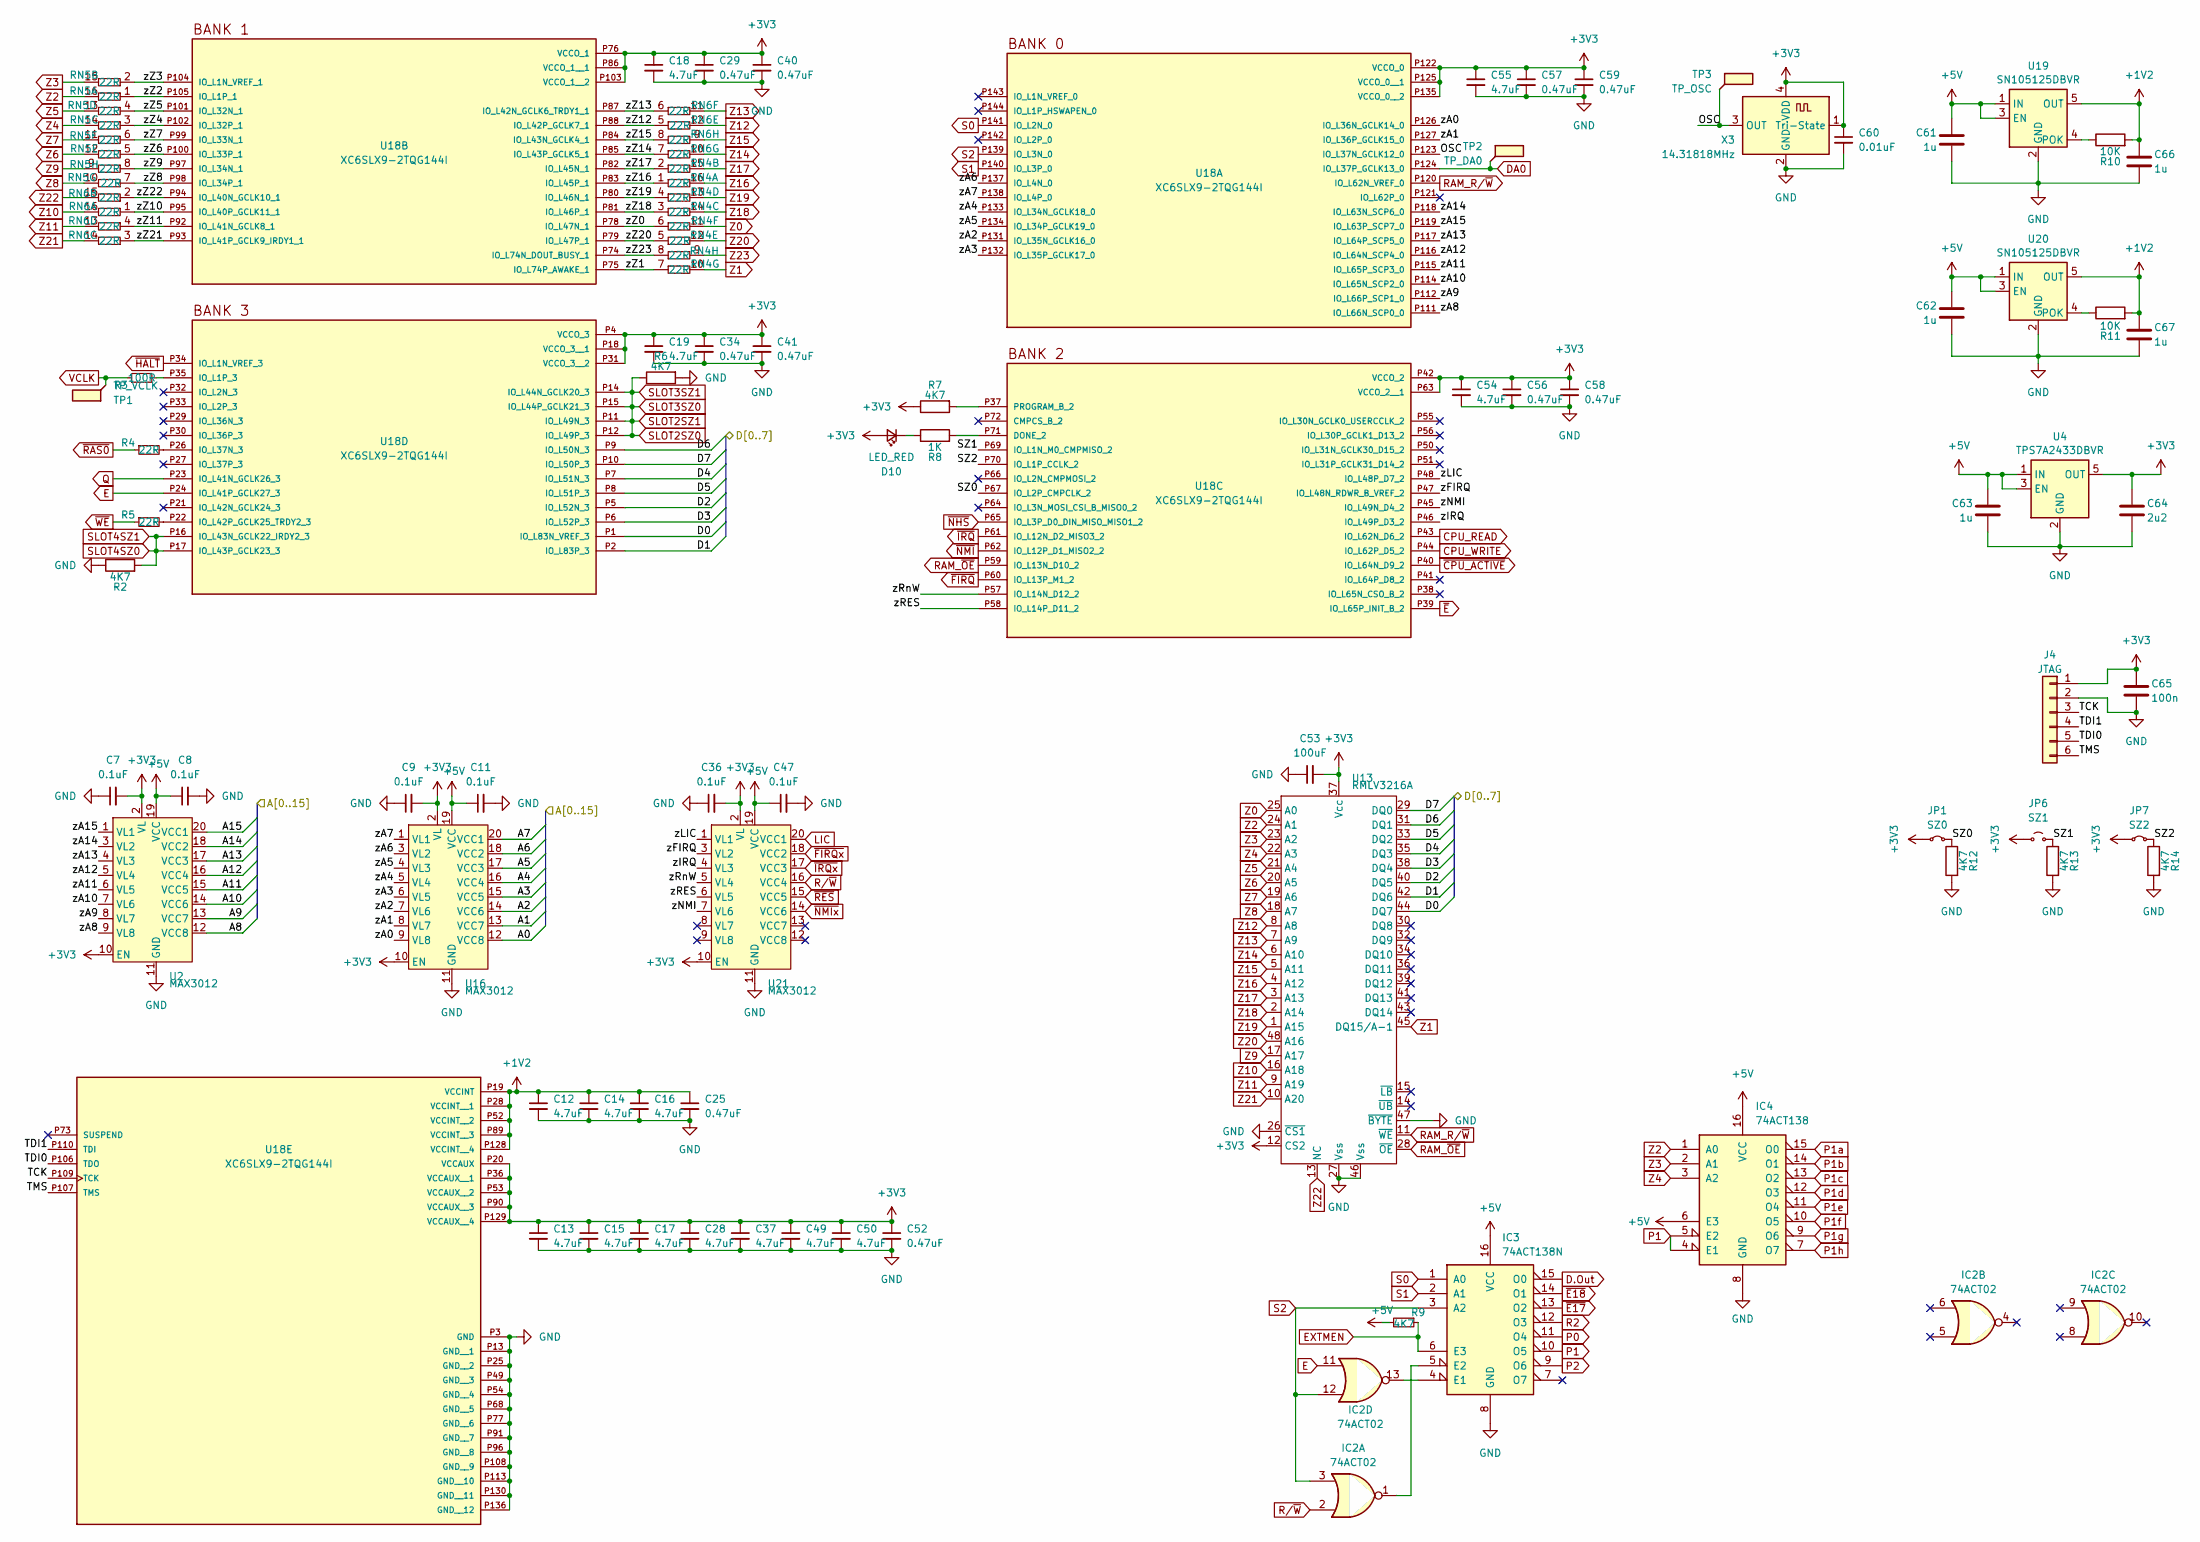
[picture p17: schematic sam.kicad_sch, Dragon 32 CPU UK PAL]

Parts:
C7, C8, C9, C11, C36, C47: 0.1uF; C_0805_2012Metric_Pad1.18x1.45mm_HandSolder; DigiKey 399-C0805C104K4RAC7800CT-ND
C12, C13, C14, C15, C16, C17, C18, C19, C28, C37, C49, C50, C54, C55: 4.7uF; C_0805_2012Metric_Pad1.18x1.45mm_HandSolder; DigiKey 399-C0805C475K4RAC7800CT-ND
C25, C29, C34, C40, C41, C52, C56, C57, C58, C59: 0.47uF; C_0805_2012Metric_Pad1.18x1.45mm_HandSolder; DigiKey 399-C0805C474K4RAC7800CT-ND
C53: 100uF; C_0805_2012Metric_Pad1.18x1.45mm_HandSolder
C60: 0.01uF; C_0805_2012Metric_Pad1.18x1.45mm_HandSolder; DigiKey 399-C0805C103K4RAC7800CT-ND
C61, C62, C66, C67: 1u; C_0805_2012Metric_Pad1.18x1.45mm_HandSolder; DigiKey 399-C0805C105K4RAC7800CT-ND
C63: 1u; C_0805_2012Metric_Pad1.18x1.45mm_HandSolder; LCSC Part C77080
C64: 2u2; C_0805_2012Metric_Pad1.18x1.45mm_HandSolder; LCSC Part C961513
C65: 100n; C_0805_2012Metric_Pad1.18x1.45mm_HandSolder; JLCPCB BOM 0
D10: LED_RED; LED_0805_2012Metric; DigiKey 67-SML-LXF0805SRD-TRCT-ND
IC2: 74ACT02; SOIC-14_3.9x8.7mm_P1.27mm; DigiKey MC74ACT02DR2GOSCT-ND
IC3: 74ACT138N; SOIC-16W_7.5x10.3mm_P1.27mm; DigiKey 74ACT138SCXCT-ND
IC4: 74ACT138; SOIC-16W_7.5x10.3mm_P1.27mm; DigiKey 74ACT138SCXCT-ND
J4: JTAG; PinHeader_1x06_P2.54mm_Vertical; JLCPCB BOM 0
JP1: SZ0; SolderJumper-2_P1.3mm_Bridged_Pad1.0x1.5mm
JP6: SZ1; SolderJumper-2_P1.3mm_Open_Pad1.0x1.5mm
JP7: SZ2; SolderJumper-2_P1.3mm_Bridged_Pad1.0x1.5mm
R2, R6, R7, R12, R13, R14: 4K7; R_0805_2012Metric_Pad1.20x1.40mm_HandSolder; DigiKey 541-4131-1-ND
R3: 100R; R_0805_2012Metric_Pad1.20x1.40mm_HandSolder; DigiKey RNCP0805FTD100RCT-ND
R4, R5: 22R; R_0805_2012Metric_Pad1.20x1.40mm_HandSolder; DigiKey RPC0805JT22R0CT-ND
R8: 1K; R_0805_2012Metric_Pad1.20x1.40mm_HandSolder; DigiKey RNCP0805FTD1K00CT-ND
R9: 4K7; R_0805_2012Metric_Pad1.20x1.40mm_HandSolder; DigiKey CF14JT4K70CT-ND
R10, R11: 10K; R_0805_2012Metric_Pad1.20x1.40mm_HandSolder; DigiKey RNCP0805FTD10K0CT-ND
RN4, RN6: 22R; SOIC-16W_5.3x10.2mm_P1.27mm
RN5: 22R; SOIC-16W_5.3x10.2mm_P1.27mm; DigiKey 4816P-T01-220LF-ND
TP1: TP_VCLK; TestPoint_Loop_D1.80mm_Drill1.0mm_Beaded
TP2: TP_DA0; TestPoint_Loop_D1.80mm_Drill1.0mm_Beaded
TP3: TP_OSC; TestPoint_Loop_D1.80mm_Drill1.0mm_Beaded
U2, U16, U21: MAX3012; TSSOP-20_4.4x6.5mm_P0.65mm; DigiKey MAX3012EUP+-ND
U4: TPS7A2433DBVR; SOT-23-5; LCSC Part C2866134
U13: RMLV3216A; TSOP-I-48_18.4x12mm_P0.5mm; DigiKey RMLV3216AGSA-5S2#AA0-ND
U18: XC6SLX9-2TQG144I; AMD-LQFP-144; DigiKey 122-1748-ND
U19, U20: SN105125DBVR; SOT-23-5; DigiKey 296-15347-1-ND
X3: 14.31818MHz; Oscillator_SMD_ECS_2520MV-xxx-xx-4Pin_2.5x2.0mm; DigiKey XC1405CT-ND

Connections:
+1V2: C12.1, C14.1, C16.1, C25.1, C66.1, C67.1, R10.2, R11.2, U18.P19 (VCCINT), U18.P28 (VCCINT__1), U18.P52 (VCCINT__2), U18.P89 (VCCINT__3), U18.P128 (VCCINT__4), U19.5 (OUT), U20.5 (OUT)
/MPU/A0: U16.12 (VCC8); also elsewhere on the board
/MPU/A1: U16.13 (VCC7); also elsewhere on the board
/MPU/A2: U16.14 (VCC6); also elsewhere on the board
/MPU/A3: U16.15 (VCC5); also elsewhere on the board
/MPU/A4: U16.16 (VCC4); also elsewhere on the board
/MPU/A5: U16.17 (VCC3); also elsewhere on the board
/MPU/A6: U16.18 (VCC2); also elsewhere on the board
/MPU/A7: U16.20 (VCC1); also elsewhere on the board
/MPU/A13: U2.17 (VCC3); also elsewhere on the board
/MPU/A14: U2.18 (VCC2); also elsewhere on the board
/MPU/A15: U2.20 (VCC1); also elsewhere on the board
/MPU/D0: U13.44 (DQ7), U18.P1 (IO_L83N_VREF_3); also elsewhere on the board
/MPU/D1: U13.42 (DQ6), U18.P2 (IO_L83P_3); also elsewhere on the board
/MPU/D2: U13.40 (DQ5), U18.P5 (IO_L52N_3); also elsewhere on the board
/MPU/D3: U13.38 (DQ4), U18.P6 (IO_L52P_3); also elsewhere on the board
/MPU/D5: U13.33 (DQ2), U18.P8 (IO_L51P_3); also elsewhere on the board
/SAM/OSC: TP3.1, U18.P123 (IO_L37N_GCLK12_0), X3.3 (OUT)
/SAM/SZ0: JP1.2 (B), R12.1, U18.P67 (IO_L2P_CMPCLK_2)
/SAM/SZ1: JP6.2 (B), R13.1, U18.P69 (IO_L1N_M0_CMPMISO_2)
/SAM/SZ2: JP7.2 (B), R14.1, U18.P70 (IO_L1P_CCLK_2)
/SAM/TCK: J4.3, U18.P109 (TCK)
/SAM/TDI0: J4.5, U18.P106 (TDO)
/SAM/TDI1: J4.4, U18.P110 (TDI)
/SAM/TMS: J4.6, U18.P107 (TMS)
/SAM/zA0: U16.9 (VL8), U18.P126 (IO_L36N_GCLK14_0)
/SAM/zA1: U16.8 (VL7), U18.P127 (IO_L36P_GCLK15_0)
/SAM/zA2: U16.7 (VL6), U18.P131 (IO_L35N_GCLK16_0)
/SAM/zA3: U16.6 (VL5), U18.P132 (IO_L35P_GCLK17_0)
/SAM/zA4: U16.5 (VL4), U18.P133 (IO_L34N_GCLK18_0)
/SAM/zA5: U16.4 (VL3), U18.P134 (IO_L34P_GCLK19_0)
/SAM/zA6: U16.3 (VL2), U18.P137 (IO_L4N_0)
/SAM/zA7: U16.1 (VL1), U18.P138 (IO_L4P_0)
/SAM/zFIRQ: U18.P47 (IO_L48N_RDWR_B_VREF_2), U21.3 (VL2)
/SAM/zIRQ: U18.P46 (IO_L49P_D3_2), U21.4 (VL3)
/SAM/zLIC: U18.P48 (IO_L48P_D7_2), U21.1 (VL1)
/SAM/zNMI: U18.P45 (IO_L49N_D4_2), U21.7 (VL6)
/SAM/zRES: U18.P58 (IO_L14P_D11_2), U21.6 (VL5)
/SAM/zRnW: U18.P57 (IO_L14N_D12_2), U21.5 (VL4)
/SAM/zZ0: RN4.6, U18.P78 (IO_L47N_1)
/SAM/zZ1: RN4.7, U18.P75 (IO_L74P_AWAKE_1)
/SAM/zZ2: RN5.1, U18.P105 (IO_L1P_1)
/SAM/zZ3: RN5.2, U18.P104 (IO_L1N_VREF_1)
/SAM/zZ4: RN5.3, U18.P102 (IO_L32P_1)
/SAM/zZ5: RN5.4, U18.P101 (IO_L32N_1)
/SAM/zZ6: RN5.5, U18.P100 (IO_L33P_1)
/SAM/zZ7: RN5.6, U18.P99 (IO_L33N_1)
/SAM/zZ8: RN5.7, U18.P98 (IO_L34P_1)
/SAM/zZ9: RN5.8, U18.P97 (IO_L34N_1)
/SAM/zZ10: RN6.1, U18.P95 (IO_L40P_GCLK11_1)
/SAM/zZ11: RN6.4, U18.P92 (IO_L41N_GCLK8_1)
/SAM/zZ12: RN6.5, U18.P88 (IO_L42P_GCLK7_1)
/SAM/zZ13: RN6.6, U18.P87 (IO_L42N_GCLK6_TRDY1_1)
/SAM/zZ14: RN6.7, U18.P85 (IO_L43P_GCLK5_1)
/SAM/zZ15: RN6.8, U18.P84 (IO_L43N_GCLK4_1)
/SAM/zZ16: RN4.1, U18.P83 (IO_L45P_1)
/SAM/zZ17: RN4.2, U18.P82 (IO_L45N_1)
/SAM/zZ18: RN4.3, U18.P81 (IO_L46P_1)
/SAM/zZ19: RN4.4, U18.P80 (IO_L46N_1)
/SAM/zZ20: RN4.5, U18.P79 (IO_L47P_1)
/SAM/zZ21: RN6.3, U18.P93 (IO_L41P_GCLK9_IRDY1_1)
/SAM/zZ22: RN6.2, U18.P94 (IO_L40N_GCLK10_1)
/SAM/zZ23: RN4.8, U18.P74 (IO_L74N_DOUT_BUSY_1)
CPU_READ: U18.P43 (IO_L62N_D6_2); also elsewhere on the board
CPU_WRITE: U18.P44 (IO_L62P_D5_2); also elsewhere on the board
D.Out: IC3.15 (O0)
DA0: TP2.1, U18.P124 (IO_L37P_GCLK13_0); also elsewhere on the board
E: IC2.11, U18.P24 (IO_L41P_GCLK27_3); also elsewhere on the board
EXTMEN: IC3.6 (E3), R9.1; also elsewhere on the board
LIC: U21.20 (VCC1)
unnamed: D10.1 (K), R8.1
unnamed: IC2.13, IC3.4 (E1)
unnamed: IC2.1, IC3.5 (E2)
unnamed: R8.2, U18.P71 (DONE_2)
unnamed: R7.2, U18.P37 (PROGRAM_B_2)
unnamed: R3.2, U18.P35 (IO_L1P_3)
unnamed: R4.2, U18.P26 (IO_L37N_3)
unnamed: R5.2, U18.P22 (IO_L42P_GCLK25_TRDY2_3)
unnamed: R10.1, U19.4 (POK)
unnamed: R11.1, U20.4 (POK)
P0: IC3.11 (O4); also elsewhere on the board
P1: IC3.10 (O5), IC4.4 (E1), IC4.5 (E2)
P1a: IC4.15 (O0); also elsewhere on the board
P1b: IC4.14 (O1); also elsewhere on the board
P1c: IC4.13 (O2); also elsewhere on the board
P1d: IC4.12 (O3); also elsewhere on the board
P1e: IC4.11 (O4)
P1f: IC4.10 (O5)
P1g: IC4.9 (O6)
P1h: IC4.7 (O7)
P2: IC3.9 (O6); also elsewhere on the board
Q: U18.P23 (IO_L41N_GCLK26_3); also elsewhere on the board
R2: IC3.12 (O3); also elsewhere on the board
RAM_R/~W: U13.11 (~WE), U18.P120 (IO_L62N_VREF_0)
RAM_~OE: U13.28 (~OE), U18.P59 (IO_L13N_D10_2)
R/~W: IC2.2, U21.16 (VCC4); also elsewhere on the board
S0: IC3.1 (A0), U18.P141 (IO_L2N_0)
S1: IC3.2 (A1), U18.P140 (IO_L3P_0)
S2: IC2.3, IC2.12, IC3.3 (A2), U18.P139 (IO_L3N_0)
SLOT2SZ0: R6.1, U18.P11 (IO_L49N_3), U18.P12 (IO_L49P_3), U18.P14 (IO_L44N_GCLK20_3), U18.P15 (IO_L44P_GCLK21_3)
SLOT4SZ0: R2.2, U18.P16 (IO_L43N_GCLK22_IRDY2_3), U18.P17 (IO_L43P_GCLK23_3)
VCLK: R3.1, TP1.1; also elsewhere on the board
Z0: RN4.11, U13.25 (A0); also elsewhere on the board
Z1: RN4.10, U13.45 (DQ15/A-1); also elsewhere on the board
Z2: IC4.1 (A0), RN5.16, U13.24 (A1); also elsewhere on the board
Z3: IC4.2 (A1), RN5.15, U13.23 (A2); also elsewhere on the board
Z4: IC4.3 (A2), RN5.14, U13.22 (A3); also elsewhere on the board
Z5: RN5.13, U13.21 (A4); also elsewhere on the board
Z6: RN5.12, U13.20 (A5); also elsewhere on the board
Z7: RN5.11, U13.19 (A6); also elsewhere on the board
Z8: RN5.10, U13.18 (A7); also elsewhere on the board
Z9: RN5.9, U13.17 (A17); also elsewhere on the board
Z10: RN6.16, U13.16 (A18); also elsewhere on the board
Z11: RN6.13, U13.9 (A19); also elsewhere on the board
Z12: RN6.12, U13.8 (A8); also elsewhere on the board
Z13: RN6.11, U13.7 (A9); also elsewhere on the board
Z14: RN6.10, U13.6 (A10); also elsewhere on the board
Z15: RN6.9, U13.5 (A11); also elsewhere on the board
Z16: RN4.16, U13.4 (A12); also elsewhere on the board
Z17: RN4.15, U13.3 (A13); also elsewhere on the board
Z18: RN4.14, U13.2 (A14); also elsewhere on the board
Z19: RN4.13, U13.1 (A15)
Z20: RN4.12, U13.48 (A16)
Z21: RN6.14, U13.10 (A20)
Z22: RN6.15, U13.13 (NC)
Z23: RN4.9
~CPU_ACTIVE: U18.P40 (IO_L64N_D9_2)
~E17: IC3.13 (O2)
~E18: IC3.14 (O1)
~E: U18.P39 (IO_L65P_INIT_B_2); also elsewhere on the board
~FIRQx: U21.18 (VCC2); also elsewhere on the board
~FIRQ: U18.P60 (IO_L13P_M1_2); also elsewhere on the board
~HALT: U18.P34 (IO_L1N_VREF_3); also elsewhere on the board
~IRQx: U21.17 (VCC3); also elsewhere on the board
~IRQ: U18.P61 (IO_L12N_D2_MISO3_2); also elsewhere on the board
~NHS: U18.P65 (IO_L3P_D0_DIN_MISO_MISO1_2); also elsewhere on the board
~NMIx: U21.14 (VCC6); also elsewhere on the board
~NMI: U18.P62 (IO_L12P_D1_MISO2_2); also elsewhere on the board
~RAS0: R4.1; also elsewhere on the board
~RES: U21.15 (VCC5); also elsewhere on the board
~WE: R5.1

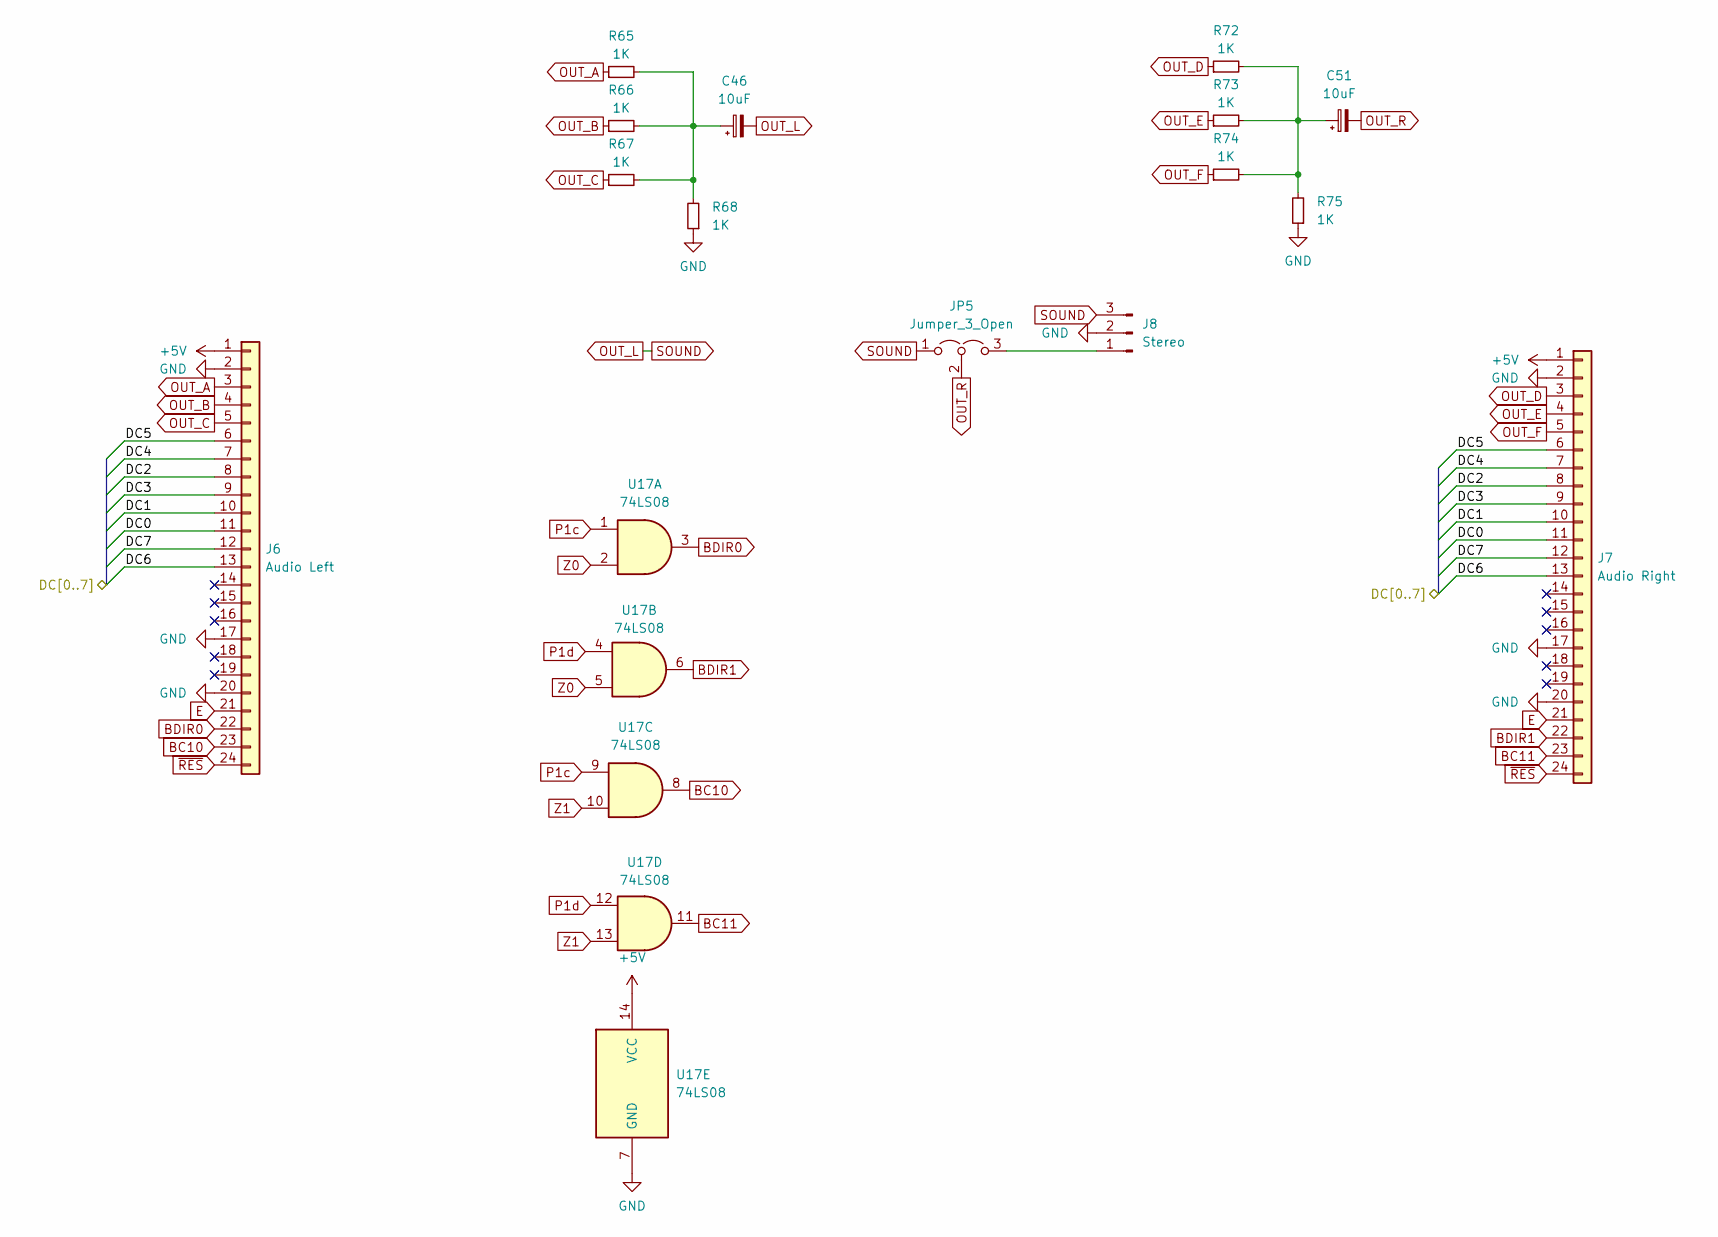
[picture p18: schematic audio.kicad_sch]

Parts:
C46, C51: 10uF; CP_Elec_5x3
J6: Audio Left; AY-QTHT
J7: Audio Right; AY-QTHT
J8: Stereo; PinHeader_1x03_P2.54mm_Vertical
JP5: Jumper_3_Open; PinHeader_1x03_P2.54mm_Vertical
R65, R66, R67, R68, R72, R73, R74, R75: 1K; R_0805_2012Metric_Pad1.20x1.40mm_HandSolder
U17: 74LS08; SO-14_3.9x8.65mm_P1.27mm

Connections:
/AUDIO/DC0: J6.11, J7.11; also elsewhere on the board
/AUDIO/DC1: J6.10, J7.10; also elsewhere on the board
/AUDIO/DC2: J6.8, J7.8; also elsewhere on the board
/AUDIO/DC3: J6.9, J7.9; also elsewhere on the board
/AUDIO/DC4: J6.7, J7.7; also elsewhere on the board
/AUDIO/DC5: J6.6, J7.6; also elsewhere on the board
/AUDIO/DC6: J6.13, J7.13; also elsewhere on the board
/AUDIO/DC7: J6.12, J7.12; also elsewhere on the board
BC10: J6.23, U17.8
BC11: J7.23, U17.11
BDIR0: J6.22, U17.3
BDIR1: J7.22, U17.6
E: J6.21, J7.21; also elsewhere on the board
unnamed: C46.1, R65.2, R66.2, R67.2, R68.2
unnamed: C51.1, R72.2, R73.2, R74.2, R75.2
unnamed: J8.1, JP5.3 (B)
OUT_A: J6.3, R65.1
OUT_B: J6.4, R66.1
OUT_C: J6.5, R67.1
OUT_D: J7.3, R72.1
OUT_E: J7.4, R73.1
OUT_F: J7.5, R74.1
OUT_L: C46.2, J8.3, JP5.1 (A); also elsewhere on the board
OUT_R: C51.2, JP5.2 (C)
P1c: U17.1, U17.9; also elsewhere on the board
P1d: U17.4, U17.12; also elsewhere on the board
Z0: U17.2, U17.5; also elsewhere on the board
Z1: U17.10, U17.13; also elsewhere on the board
~RES: J6.24, J7.24; also elsewhere on the board

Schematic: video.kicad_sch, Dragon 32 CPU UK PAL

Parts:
J1: Video Output Female; PinSocket_1x05_P2.54mm_Vertical
J2: Board Interconnect Female; PinSocket_2x11_P2.54mm_Vertical
J3: Conn_02x08_Odd_Even; PinSocket_2x08_P2.54mm_Vertical
PL6: Conn_01x09_Male; Molex_KK-396_A-41791-0009_1x09_P3.96mm_Vertical; DigiKey 2057-LHD-09-TS-ND

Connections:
+12V: PL6.9; also elsewhere on the board
-5V: J1.3, PL6.7; also elsewhere on the board
/MPU/D0: J2.3; also elsewhere on the board
/MPU/D1: J2.5; also elsewhere on the board
/MPU/D2: J2.7; also elsewhere on the board
/MPU/D3: J2.9; also elsewhere on the board
/MPU/D5: J2.13; also elsewhere on the board
BIAS: J1.1, PL6.1
CSS: J2.19; also elsewhere on the board
DA0: J2.6; also elsewhere on the board
E: J3.16; also elsewhere on the board
GM0: J2.14; also elsewhere on the board
GM1: J2.12; also elsewhere on the board
GM2: J2.10; also elsewhere on the board
OUT_L: PL6.3; also elsewhere on the board
P1b: J3.12; also elsewhere on the board
R/~W: J3.14; also elsewhere on the board
VCLK: J2.18; also elsewhere on the board
VID OUT: J1.4, PL6.4
~A/G: J2.20; also elsewhere on the board
~FS: J2.22; also elsewhere on the board
~NHS: J2.8; also elsewhere on the board
~RAS0: J2.16; also elsewhere on the board

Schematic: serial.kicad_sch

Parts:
C2, C20, C21, C24: 10u; CP_Elec_5x5.3
C10: 100n; C_0805_2012Metric_Pad1.18x1.45mm_HandSolder; not fitted
PL9: Serial; DIN-7_DELTRON_671-0701_Horizontal; not fitted
R44, R53: 4K7; R_0805_2012Metric_Pad1.20x1.40mm_HandSolder; DigiKey CF14JT4K70CT-ND; not fitted
U7: MAX232; SOIC-16_3.9x9.9mm_P1.27mm; DigiKey 296-14619-1-ND
U12: W65C51; PLCC-28_SMD-Socket; not fitted
X2: 1.8432MHz; Crystal_HC18-U_Horizontal_1EP_style2; not fitted

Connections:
+12V: R44.2; also elsewhere on the board
-5V: R53.2; also elsewhere on the board
/AUDIO/DC0: U12.18 (D0); also elsewhere on the board
/AUDIO/DC1: U12.19 (D1); also elsewhere on the board
/AUDIO/DC2: U12.20 (D2); also elsewhere on the board
/AUDIO/DC3: U12.21 (D3); also elsewhere on the board
/AUDIO/DC4: U12.22 (D4); also elsewhere on the board
/AUDIO/DC5: U12.23 (D5); also elsewhere on the board
/AUDIO/DC6: U12.24 (D6); also elsewhere on the board
/AUDIO/DC7: U12.25 (D7); also elsewhere on the board
/Serial/RxD: U7.12 (R1OUT), U12.12 (RXD)
/Serial/TxD: U7.11 (T1IN), U12.10 (TXD)
/Serial/xRxD: PL9.5, U7.13 (R1IN)
/Serial/xTxD: PL9.6, U7.14 (T1OUT)
/Serial/x~CTS: PL9.2, U7.8 (R2IN)
/Serial/x~DTR: PL9.4, U7.7 (T2OUT)
/Serial/~CTS: U7.9 (R2OUT), U12.9 (~CTS)
/Serial/~DTR: U7.10 (T2IN), U12.11 (~DTR)
E: U12.27 (E); also elsewhere on the board
unnamed: PL9.3, R44.1
unnamed: PL9.7, R53.1
unnamed: C2.1, U7.1 (C1+)
unnamed: C2.2, U7.3 (C1-)
unnamed: C21.1, U7.4 (C2+)
unnamed: C21.2, U7.5 (C2-)
unnamed: C20.1, U7.2 (VS+)
unnamed: C24.2, U7.6 (VS-)
unnamed: U12.6 (1XTAL), X2.1
unnamed: U12.7 (2XTAL), X2.2
P0: U12.3 (~CS1); also elsewhere on the board
R/~W: U12.28 (R/~W); also elsewhere on the board
Z0: U12.13 (RS0); also elsewhere on the board
Z1: U12.14 (RS1); also elsewhere on the board
Z2: U12.2 (CS0); also elsewhere on the board
~IRQx: U12.26 (~IRQ); also elsewhere on the board
~RES: U12.4 (~RESET); also elsewhere on the board

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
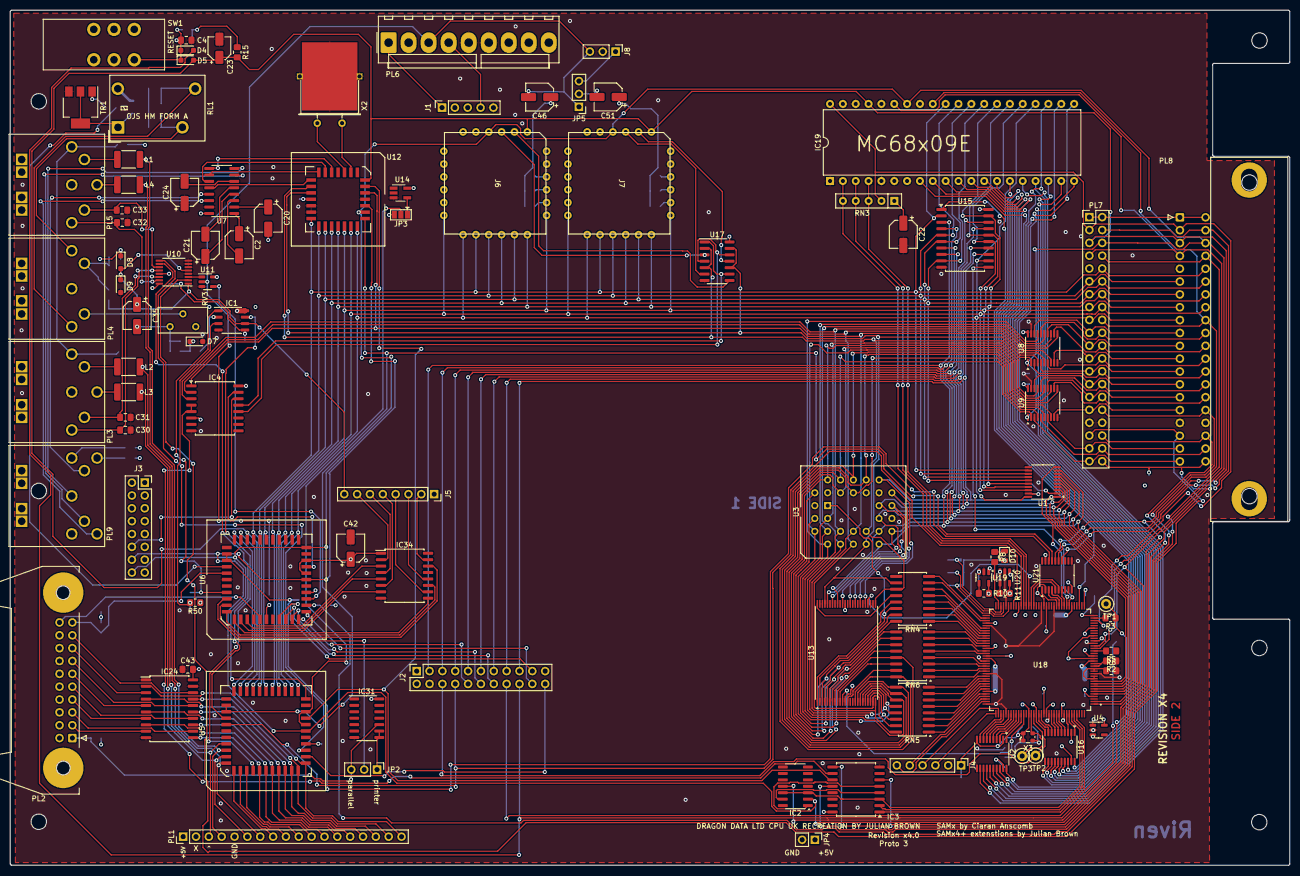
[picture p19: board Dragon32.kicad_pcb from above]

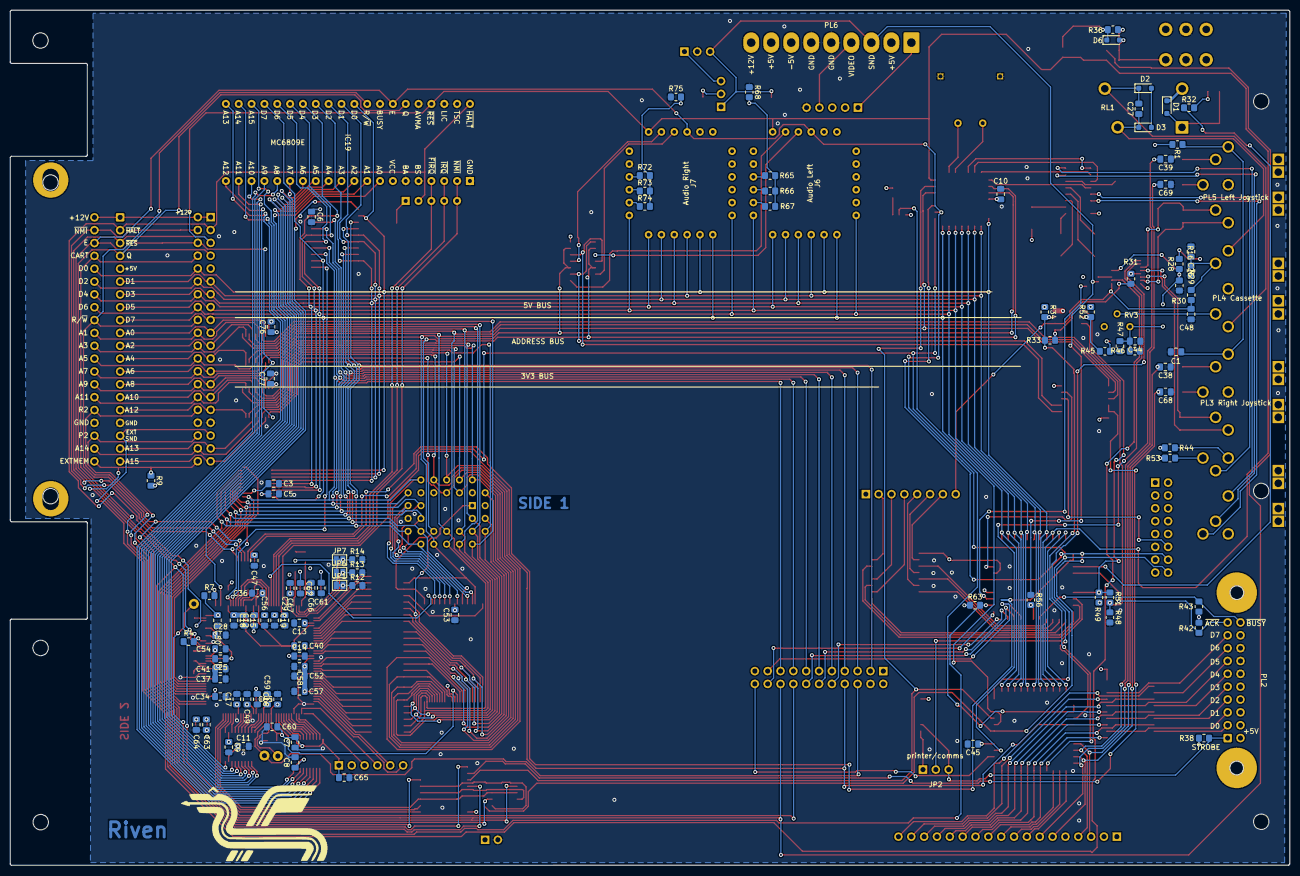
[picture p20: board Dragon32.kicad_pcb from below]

Board: 4 copper layers, 253.0 x 169.1 mm, 198 parts (100 on the bottom side), 295 nets.

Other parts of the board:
U10: 4052; TSSOP-16_4.4x5mm_P0.65mm
U11: TS5A3166DBVR; SOT-23-5

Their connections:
CB2: U11.4; also elsewhere on the board
ESND: U10.2 (Y2); also elsewhere on the board
unnamed: U10.3 (Y), U11.1
OUT_L: U11.2; also elsewhere on the board

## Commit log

2023-12-02 move to samx4
    [Dragon32.kicad_sch, mpu.kicad_sch, pia1.kicad_sch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]
2023-12-02 rework board
    [Dragon32.kicad_sch, mpu.kicad_sch, pia1.kicad_sch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]
2023-12-10 serial wiring
    [Dragon32.csv, Dragon32.kicad_pcb, Dragon32.kicad_sch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]
2023-12-10 add audio circuits
    [Dragon32.kicad_pcb, Dragon32.kicad_sch]
2023-12-11 complete audio routing
    [Dragon32.kicad_pcb, audio.kicad_sch, serial.kicad_sch]
2024-01-07 fix OE timing on SRAM
    [Dragon32.csv, Dragon32.kicad_pcb, pia1.kicad_sch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]
2024-01-07 update page info
    [Dragon32.kicad_pcb, Dragon32.kicad_sch, audio.kicad_sch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]
2024-03-04 move -5v
    [Dragon32.kicad_pcb, sam.kicad_sch, video.kicad_sch]
2024-07-07 switch to fpga
    [Dragon32.kicad_pcb, Dragon32.kicad_sch, audio.kicad_sch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]
2024-07-11 rework traces for FPGA
    [Dragon32.kicad_pcb, cartridge.kicad_sch, mpu.kicad_sch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]
2024-07-11 remove via in pad
    [Dragon32.kicad_pcb]
